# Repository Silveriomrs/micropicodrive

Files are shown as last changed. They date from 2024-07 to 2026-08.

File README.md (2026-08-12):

# MicroPicoDrive
 _An internal replacement for the Sinclair QL Microdrive_

---

UPDATE 12/08/2026

> [!NOTE]
> _New revisions of the driver & cartridges with extra EMI & electrical protection and improving signals. Firmware revision 0.14 improved & stable. Firmware & driver tested, tested last cartridge sub-version 'e' for 4 weeks. Added 3D case (STL) created by Jbizze for short cartridge version to its link_.

> [!TIP]
> All material (Gerbers, BOM, etc) & user guides at the bottom of the page.
---

This branch is for the new 1.4 version of the MicroPicoDrive.
This version was created by Silverio MRS (AKA Popopo) from [Dr. Gusman's original version](https://github.com/gusmanb/micropicodrive).

<p align="center">
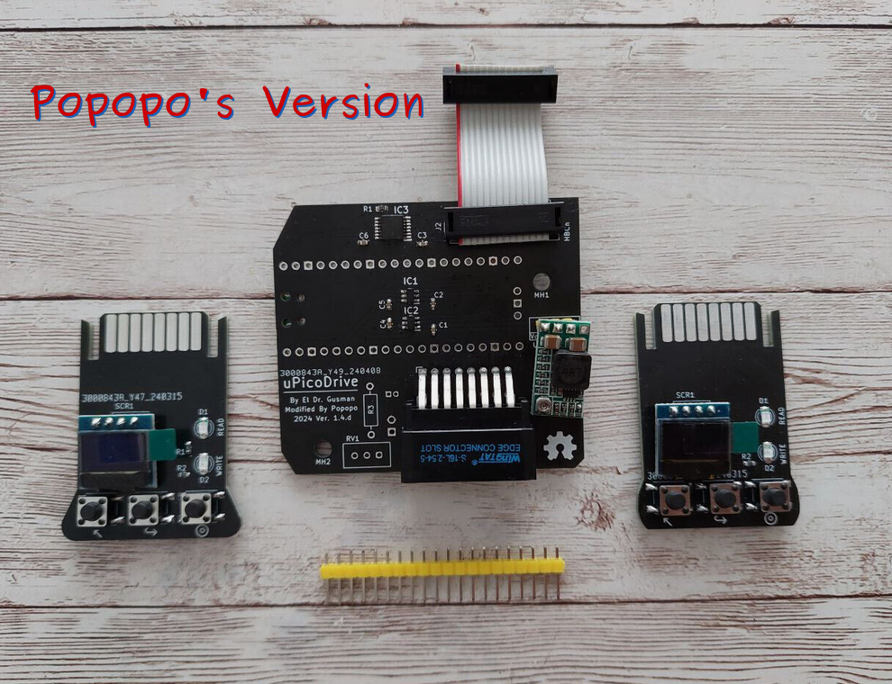
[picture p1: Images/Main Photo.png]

</p>

The image above shows the main driver unit and the 2 cartridges versions with long and short wings (_handles_). Long wings allows to manipulate the cartridge easily reducing mechanical pressure. Shorts instead gives an old fashion shape and allows to be stored into the old (used) black boxes of QL time. Also wearing the 3D case created by Jbizze for the short version cartridge.

<p align="center">
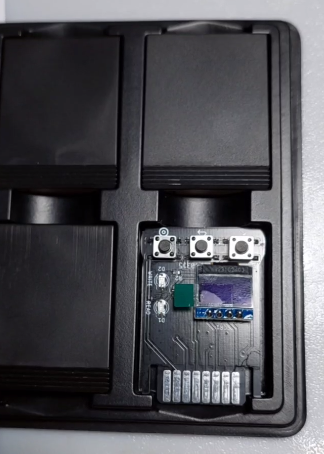
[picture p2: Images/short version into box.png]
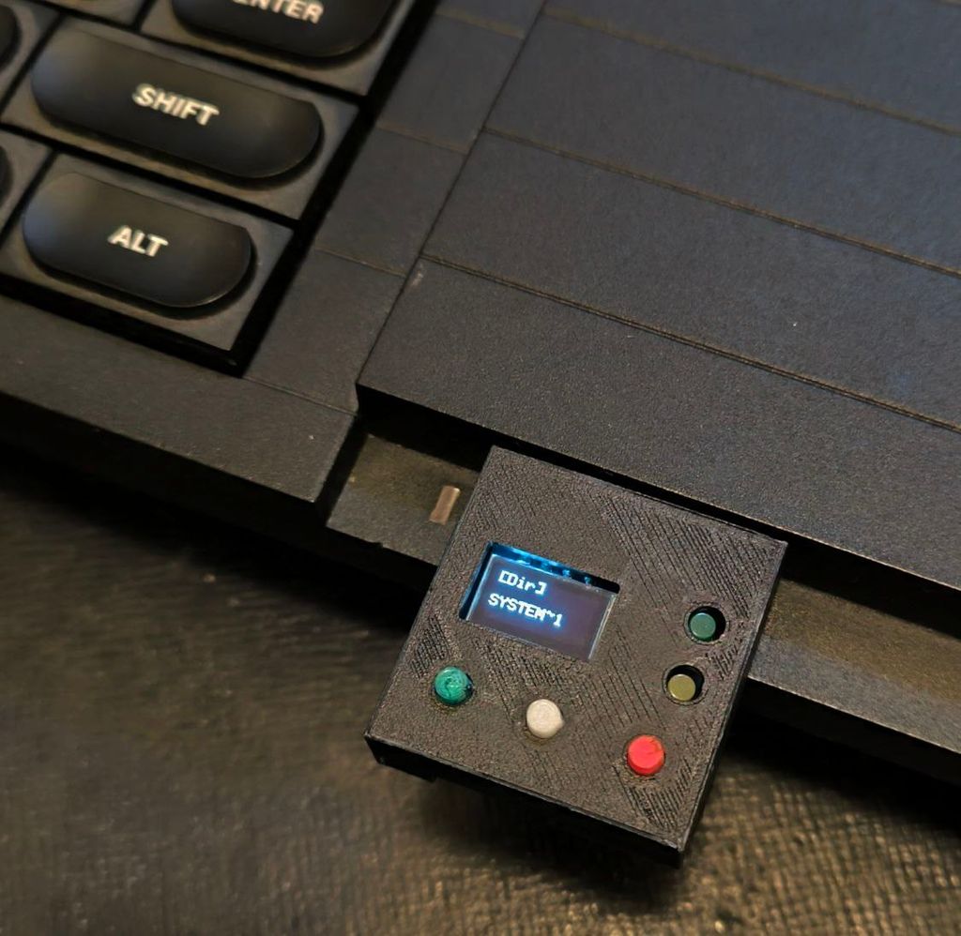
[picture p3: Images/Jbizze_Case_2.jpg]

</p>

---
The next link is a fast view with a demo of the device [Short video demo on Youtube](https://youtu.be/dqscsMP1UB8).

---
_Schema of the driver unit that goes inside the QL._

<p align="center">
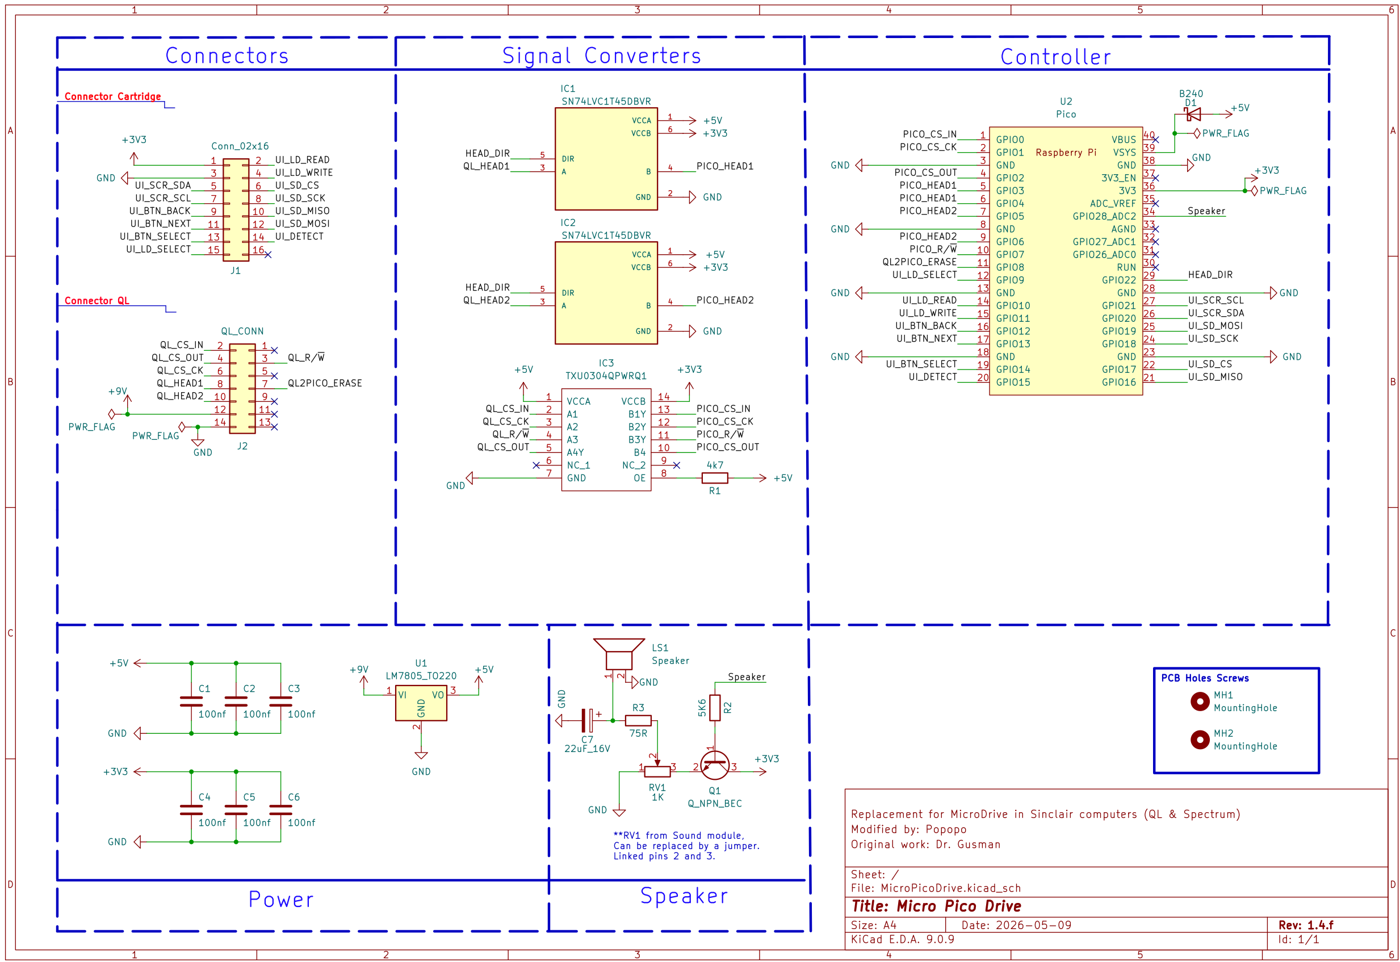
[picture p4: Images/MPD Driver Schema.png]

</p>

---
_Schema of the cartridge that host the microSD and interact with the user._

<p align="center">
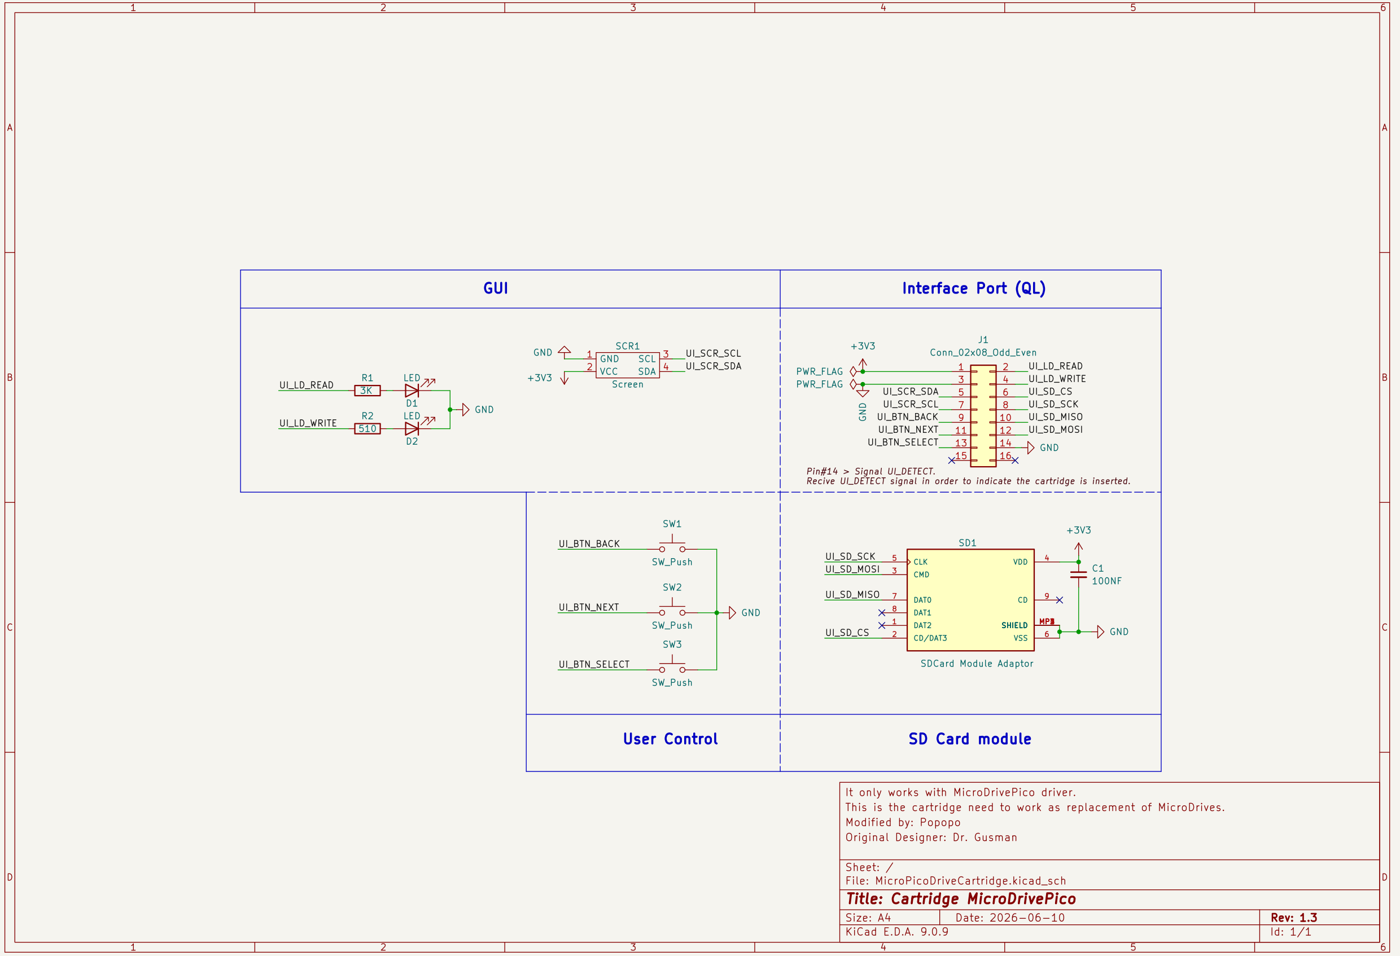
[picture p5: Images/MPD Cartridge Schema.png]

</p>

# Overview
The project was born to give a solution to the old [ZX Microdrive](https://en.wikipedia.org/wiki/ZX_Microdrive) data systems that relies on tape technology. Due to all those system are more than 50 years old and doesn't exist replacements. This system needed a modern replacement stable, very easy to use, flexible and cheap.

The solution presented relay on Hardware and Software combination. With an OpenSource philosophy that could be easily be continued by thirds parties if needed.

The OpenSource & OpenHardware philosophy also responds to the main idea of allowing everyone to built at any time with inexpensive materials, modify or implements different features.

# Objectives of the project
The project was born with the simple goal to be something that anyone could afford and built, what was exceed by far. Yet, there were some details that make the solution not so universal for everyone (_IMO_). Here is where our story begins.

The point is to exploit all the potential of the concept, increasing the number of features of the device, closer to the Gotek concept but powered up with a lot of amazing and desired features.

The first approach was a full success. Whatever in some design points it was limited:
1. It needs some skills and technical hardware acknowledged the system in advance before to build it.
2. Some users with visual difficulties found it unusable due to the small screen. 
3. If you want to distribute it, you can't without knowing previously where the final user want to place it.

Not only **the hardware have been re-shaped**, but **the code/firmware has been refactored, documented (even more) and modularized** in a way that the skills requirements to modify it, become affordable with lower programming skill than before.

It makes sense if the idea is to get chances of scalability and maintenance by the community or recycle the code/hardware in other similar projects.

## Changes over the original project
**New 1.4 design changes:**

+ Place it in any position (MDV_1 or MDV_2) without physical modification.
+ IDC Cable now go straight to the connector on the QL MB.
+ Removed Status LED from Cartridge due to redundancy information with QL Case LED.
+ Add MicroSD footprint to the Cartridge. From now on, it will be cheaper & elegant to build it up.
+ The board is shorter than original one reducing possible case clashes.
+ RaspBerryPi Pico now is soldered on the bottom of the Driver PCB.
+ The Power regulator has changed the place, allowing to the board be placed in any position (MDV_1 or MDV_2).
+ Solved problem with QL Speaker.
+ Solved problem with QL metal chassis under keyboard.
+ Solved problem with right lateral QL case and the regulator.
+ Sound System ready for sound emulation or new features related with it (Working in progress).
+ Added decoupling capacitors to make signals more stable for oLED & mSD.
+ Added schottky diode on the driver that allows program it without disconecting from the main QL PCB. For extra it gives extra protection.
+ Cartridges now has pads retraived for power lines and detection.

## What is coming (TODO functionalities)

Majority of users find the device functional and accomplish their expectations, however still it keeps some nice surprises to powering it up. **All of then can be activated optionally (_opt_)**.

 **Software/firmware**
- [x] Config file to customize preferences (opt).
- [x] New screen modes with bigger fonts (opt).
- [x] Capability of defining a default image to load when turning on the QL or inserting the cartridge (opt).
- [ ] Direct writing (optional).
- [ ] Direct control from the QL OS over the storage system (mSD).

 **Hardware**
- [ ] Sound emulation of the motor (WiP) (opt).
- [ ] MIDI player (WiP) (opt).
- [ ] Bluetooth cartridge and its APP to load images from other devices (PC, Phone, Tablet...) (opt).

### Some extra add-ons that could come
- [ ] External version of the MDP.
- [ ] Interface I MDP version.

---

# Audio visual material
The next videos were made in order to make easier to everyone the understanding about the integration and use on Sinclair QL systems. 
- [Presentation](https://youtu.be/yyiCoWN6E_A) of the project and its initial goals.
- [How to install it](https://youtu.be/CpoAiAcQRLA) points to keep in mind to not damage your Sinclair QL when installing the MDP into it.
- [User's Guide I](https://youtu.be/wyJjXfhqH4E) user's guide to change the firmware, prepare the SD, customize your preferences & browse it.
- [User's Guide II](https://youtu.be/AZIg0KIsFko) shows how to use the basis functions of the MDTools to create a new MDV image, also it shows the most common mistakes.

# Gerbers, Firmware & more 
To download and make the devices on your own using my design you can access to the Gerbers and Firmwares at the release section:
[Releases Gerbers & Firmware](https://github.com/Silveriomrs/micropicodrive/releases/tag/v1.4)

For detailed information about revisions of drivers or cartridges go to see: [Gerbers Descriptions Section](https://github.com/Silveriomrs/micropicodrive/tree/1.4/Hardware%201.4%20(By%20Popopo)/Gerbers)

For i/BOM check directory: [Schmems & i/BOMs](https://github.com/Silveriomrs/micropicodrive/tree/1.4/Hardware%201.4%20(By%20Popopo)/Schems%20&%20BOMs)

For 3D case created by Jbizze for short cartridge version: [STL from Thingverse](https://www.thingiverse.com/thing:6886864) or to Download directly: [Releases Gerbers & Firmware](https://github.com/Silveriomrs/micropicodrive/releases/tag/v1.4)

<p align="center">
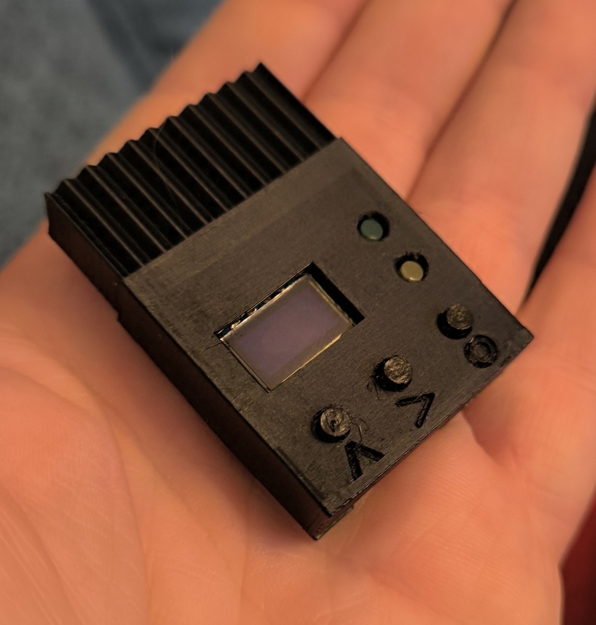
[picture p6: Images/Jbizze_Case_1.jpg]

</p>

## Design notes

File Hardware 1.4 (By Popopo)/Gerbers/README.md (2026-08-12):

# Gerbers Description
 _Secction to describe each Gerber option_

---

UPDATE 12/08/2026

> [!NOTE]
> _New revisions of the driver (h) & cartridges (e) with extra EMI & electrical protection and improving signals._.

There system is compound by a driver and its cartridge. It is always possible to improve somehow some elements or factors, so a alive project requires time to time some new releases (when they are justified). 

Sometimes changes are to improve signals, ESD/EMI factors, or power. In other cases it is to bring to the users more options and better implementation/building.

## Driver
Always the last version will result in the best option, but sometimes those changes are not necesesary. If you don't know what to use, choose the newest version. If you are happy with lower protection level or not using some hardware elements you know won't be useful for you (that means you have a good control of what you are doing), choose the alternative from available Gerbers.

<p align="center">
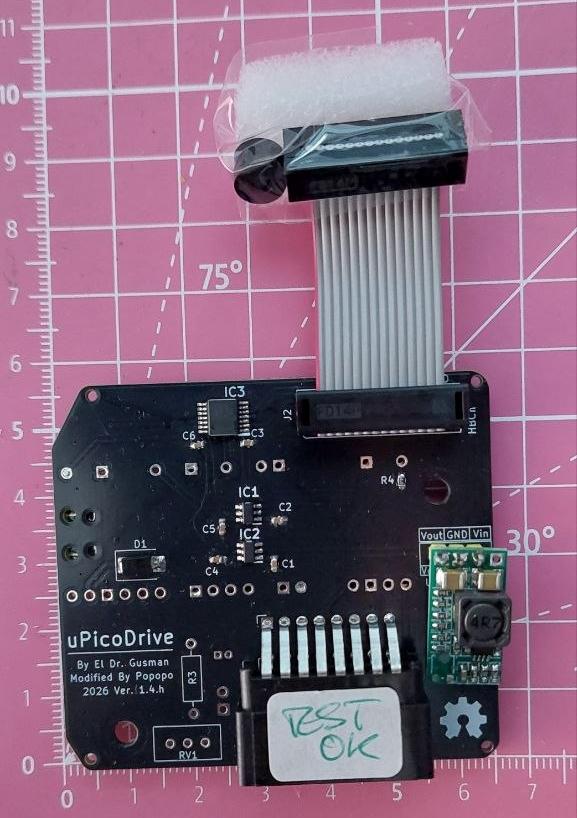
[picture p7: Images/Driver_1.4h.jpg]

</p>

## Cartridge
Here is where a final user could feel confuse due to variety of options :) , let's see it in an direct & easy way.

**There are 2 main different shapes** for cartridge which main difference is the size of the handles: **Short** and **Large** one. 

<p align="center">
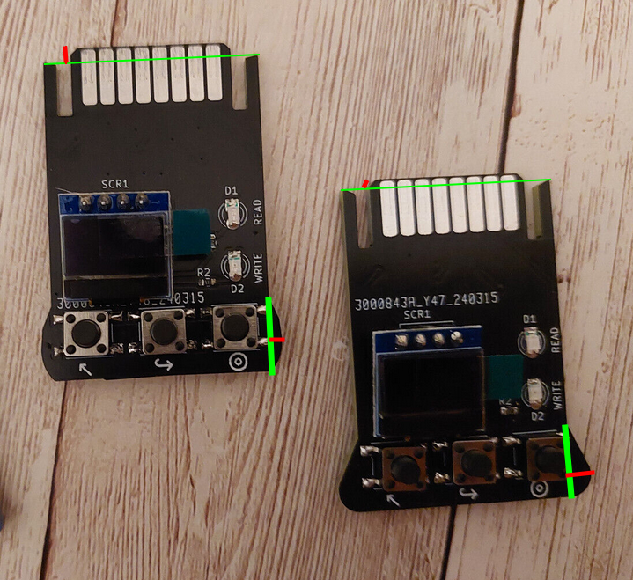
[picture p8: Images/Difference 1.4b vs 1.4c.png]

</p>

The short is more than enough to handle it easily and fits into the old black plastic box where Sinclair used to give PSION software.

The large is easier to extract/insert than the short one, for hands like mine it is nicer. 

How it is designed allows you to use SMD Leds or TH Leds (giving more retro feeling). So when mounting the LEDs you can choose what suits more more to your personality. Keep in mind that schemas reflects resistos values for the LEDs acording to the specs of the used LEDs by myself. TH versions may be happy with 1K resistors but always check it out by yourself according to luminance, max current and max current that RP2040 may source.

<p align="center">
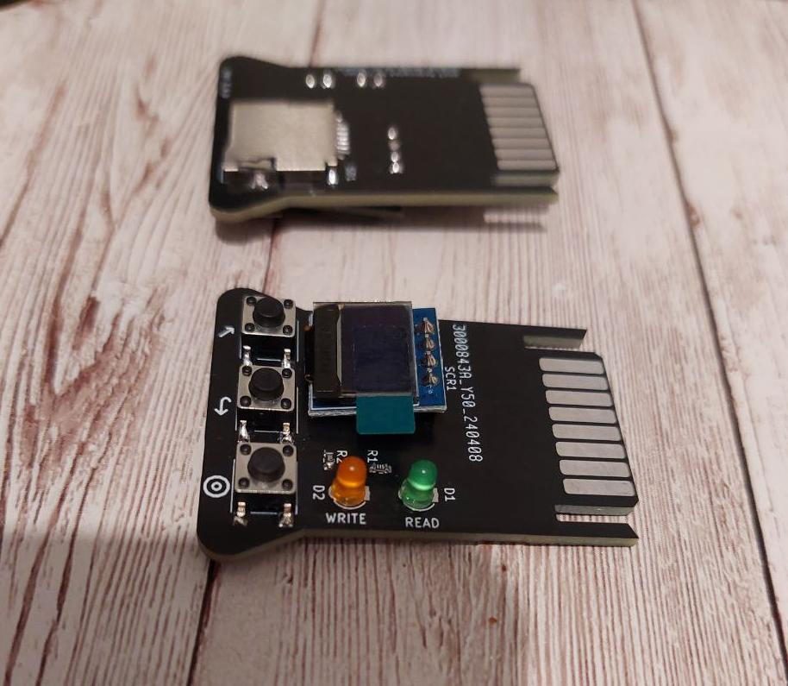
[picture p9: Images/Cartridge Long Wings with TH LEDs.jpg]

</p>

Finally, recently I have made some changes for cartridges in order to improve electrical manipulation, so a good part of the pads that were connection to the EDGE socket now are retreived in order to ensure Power Lines are connected before the signals. It is by now working great, but old version has been working for 3 years with non stop (and with HASL finishing).

<p align="center">
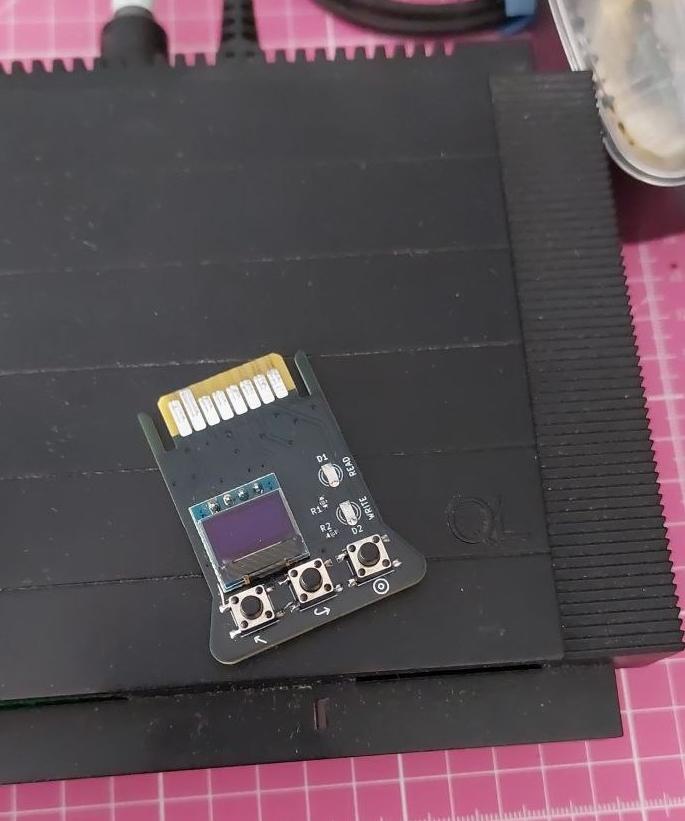
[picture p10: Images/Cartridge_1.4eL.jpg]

</p>

**Pros**: Safer electrically case now power pads connect firstly (specially GDN), the EDGE contacts now scratch less copper/HASL surface when inserting/removing operation and now it goes on a FR4 fiber that is harder to scratch than regular pads.

**Cons**: Has not been tested for years like previous one.

If you are going to produce your own PCBs or use any maker like PCBWay or JLCPCB, you can choose a better finish for EDGE connector and PADs, like ENIG or HARD Gold. But be aware, IMHO that is not justified at all, is too expensive for the service of this system that have been working for years without any problem at innexpensive price. HASL is more than enough like all our machines have been produced (back ports on ZX, QL, MSX, CPC... long list). I recommend HASL: cheap & more than good for the service.

Trust me, you will more than happy with any option you choose. :)

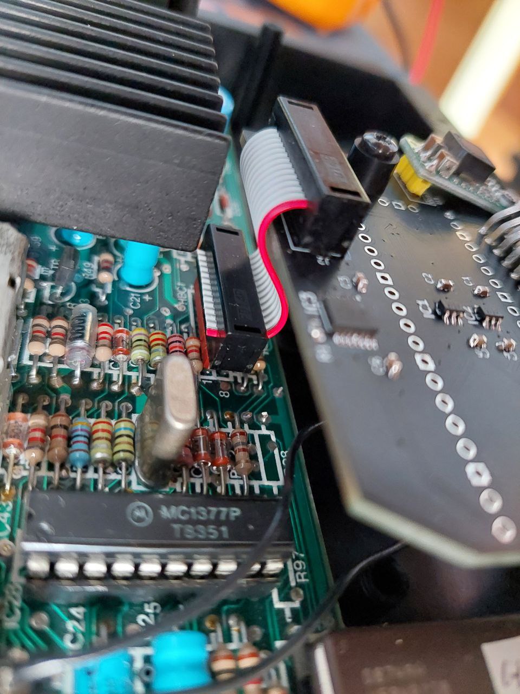
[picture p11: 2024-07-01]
Images/Insalled MDP Lateral.jpg

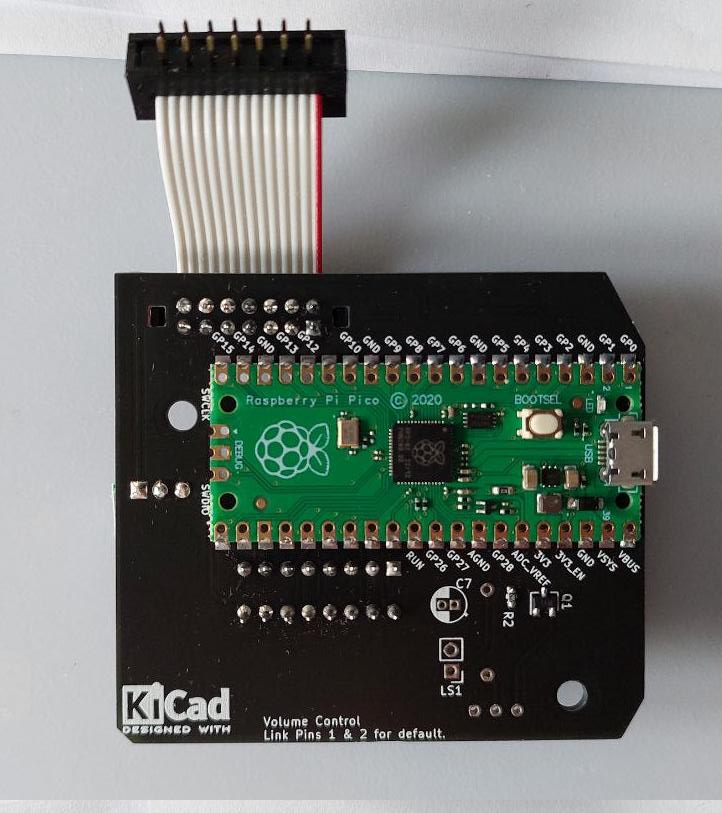
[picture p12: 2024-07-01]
Images/Drive bottom.jpg

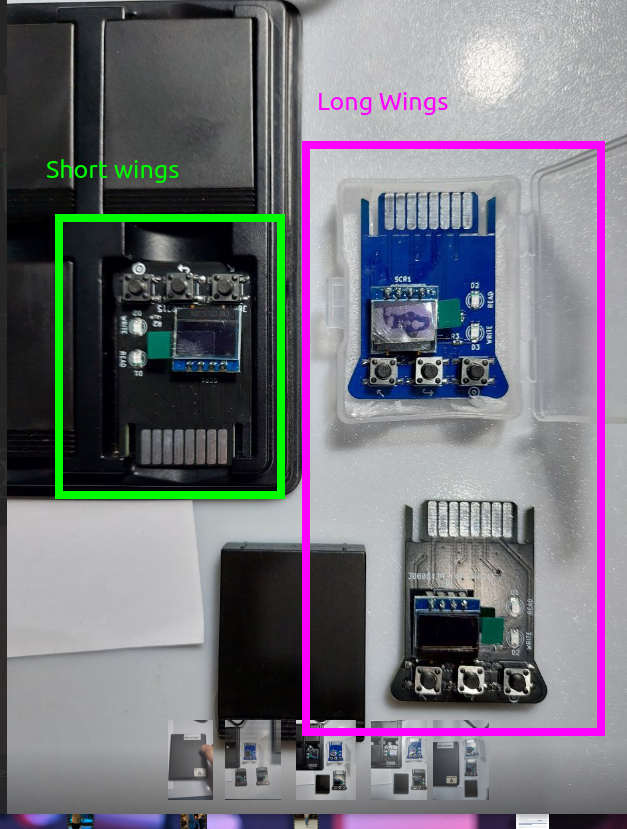
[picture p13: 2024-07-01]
Images/Long vs short wings.png

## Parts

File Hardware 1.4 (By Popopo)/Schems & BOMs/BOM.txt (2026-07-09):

--Main unit--

C1 to C6: 100nf, 0603
R1: 4k7, 0603
R4: 1K, 0603
IC1, IC2: SN74LVC1T45DBVR
IC3: TXU0304PWR
U1: 7805 TO220 or DC/DC buck module
D1:	B240 D_SMB (higly recommended but may be 1A diode instead 2A. It is optional and may be skiped: linking both sides with a jumper)
U2: Raspberry pico
J1: Card edge connector, 2x8p, 2.54mm, curved pin.
J2: Male IDC, 2x7p, 2.54mm (check assembly instructions for more details)

(Optional sound pre.module)
R2: 5K6, 0603
Q1: NPN MMBT3904 / 2N3904 1AM SOT23  40V 200mA

--Cartridge--

R1 to R2: 1k, 0603  (It depends on the specs of each led)
C1: 100nf, 0603
SW1 to SW3: SMD microswitch push button
SCR1: 0'49" SD1306 module
D1 to D2: 3mm LED (green and yellow/red)
SD1: SD card socket module

--Buy links--

SN74LVC1T45:		https://es.aliexpress.com/item/1005004345377244.html
TXU0304PWR:  		https://es.aliexpress.com/item/1005004929752779.html
DC/DC buck converter: 	https://es.aliexpress.com/item/1005005343434991.html
Card edge connector:	https://es.aliexpress.com/item/1005001884522039.html
IDC connector:		https://es.aliexpress.com/item/1005001835803614.html
Screen module:		https://es.aliexpress.com/item/1005003874700775.html
SD card module:		https://es.aliexpress.com/item/32791255542.html

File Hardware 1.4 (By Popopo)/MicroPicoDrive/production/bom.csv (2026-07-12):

Designator | Footprint | Quantity | Value | LCSC Part #
C1, C2, C3, C4, C5, C6 | 0603 | 6 | 100nf
C7 | CP_Radial_D4.0mm_P1.50mm | 1 | 22uF_16V
D1 | D_SMB | 1 | B240
IC1, IC2 | SOT95P280X145-6N | 2 | SN74LVC1T45DBVR
IC3 | TXU0304QPWRQ1 | 1 | TXU0304QPWRQ1
J1 | Edge_connector_02x08 | 1 | Conn_02x16
J2 | CONN_IDC_2x7 | 1 | QL_CONN
LS1 | PinHeader_1x02_P2.54mm_Vertical | 1 | Speaker
MH1, MH2 | MountingHole_3.5mm_safe_screw_area | 2 | MountingHole
MH_S1, MH_S2, MH_S3, MH_S4 |  | 4 | MountingHole
Q1 | SOT-23W | 1 | Q_NPN_BEC
R1 | 0603 | 1 | 4k7
R2 | 0603 | 1 | 5K6
R3 | R_Axial_DIN0207_L6.3mm_D2.5mm_P10.16mm_Horizontal | 1 | 75R
R4 | 0603 | 1 | 1K
RV1 | Potentiometer_Bourns_3296W_Vertical | 1 | 1K
U1 | TO-220-3_Vertical | 1 | LM7805_TO220
U2 | RPi_Pico_SMD_TH | 1 | Pico

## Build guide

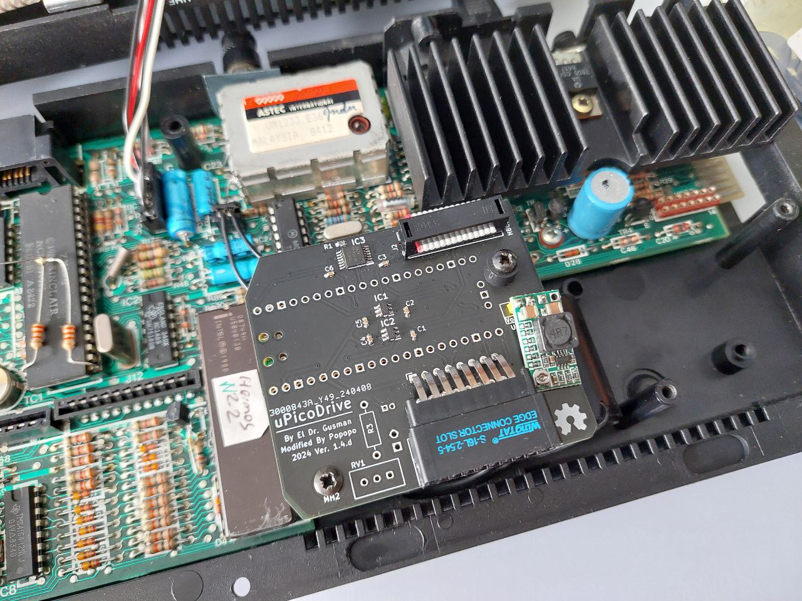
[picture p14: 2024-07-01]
Images/Installed MDP Top.jpg

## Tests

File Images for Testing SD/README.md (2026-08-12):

# Description of Images (MDV & MDP)
## _Overview_

> [!NOTE]
> _Images served only for testing purpose_

The microdrives images presented here are only for testing purpose. Thus you can find software ready to load into your QL system and others that need some works with [MDTools (From Dr. Gusman)](https://github.com/gusmanb/micropicodrive/releases/tag/V1.0.0.0) or another similar tool.

In particular part of the PSION software is not prepared yet to be loaded successfully in a real QL with Minerva ROM (but Abacus). It allows you to understand the complexity and how MDV images are required to be adapted for emulators or some devices. What means it is not related with an specific hardware solution but how datas are modified by some OSes (_ie. MS Windows_) when they are stored in its file system or even the QL ROM you are using.

The idea is to give few images to play around directly with QL and enjoy the MicroDrivePico solution (also name here as MPD). Others to learn to control the MDTools and how the QL ecosystem fight between different formats and issues from a highly complex legacy reasons.

If you are new in QL ecosystem, be aware that due to some OS treatment with storage systems (MS Windows mainly) it requires some "headers" or extra info related with data space and "Magic Fields" that exceed the purpose of this info. All that can be solved with the mentioned tools above.

Also, for newbies there is a empty and formatted image that you can use (copy and paste) to use like real Microdrives to save your data or use like you were using real one.

I hope you're enjoying this beautiful solution. :)

## Directory: Main
No particular hardware needs for those images.

| Image | Ready? | Type | Overview |
| --- | :--: | :--: | ---- |
| ABACUS.MDV | Yes | Office | Developed by PSION software |
| Chess.mdv | Yes | Game |  |
| pacman_patched | No | Game | The image has not right checksum |
| Pitman.MDV | Yes | Game | Developed by Andrei |
| Space Invaders(PD).mdv | Yes | Game |  |
| MyBasic.mdv | Yes | Util | Basic cartridge with a Basic sample |
| newcart.mdv | Yes | Util | Formatted MDV image for your use |
| **CONFIG.CFG** | Yes | Util | _Optional file_ **required to customize the device** |

## Directory: PSION_4
All those belongs to PSION suit. All of them work properly in a stock QL with MDPs. They have the headers 'fixed' with the data attribute saved. They could serve like comparation with the structure image with their twins into the Fail folder.

| Image | Ready? | Type | Overview |
| --- | :--: | :--: | ---- |
| ABACUS.MDV | Yes | Office | Developed by PSION software |
| ARCHIVE.MDV | Yes | Office | Developed by PSION software |
| EASEL.MDV | Yes | Office | Developed by PSION software |
| QUILL.MDV | Yes | Office | Developed by PSION software |

## Directory: FAIL
All those belongs to PSION suit. Those images are to test and play around with convertir MDVs subformats and doesn't work without 'fix' them. Specially to use Dr. Gusman tools or Johan Engdhal's tool. 

| Image | Ready? | Type | Overview |
| --- | :--: | :--: | ---- |
| ARCHIVE.MDV | No | Office | Developed by PSION software |
| EASEL.MDV | No | Office | Developed by PSION software |
| QUILL.MDV | No | Office | Developed by PSION software |

## Directory: Demos
**Some hardware requirements could be need**. For example: Sound cards, expansion cards, memory expansion, new versions of the demos (due to it presented bugs in the time where they were published), etc. You should be aware of those matters and find the requirements/updates to play around with them.

This directory contains some others with files of many kinds to play around about converting them into MDV images, changing headers and so on.

| Image | Ready? | Type | Overview |
| --- | :--: | :--: | ---- |
| m86K24 | ? | Demo | Sound card/Specific ROM? |
| smfxteam.mdv | ? | Demo | Sound card/Specific ROM? |
| qldrive11 | X | Dir | Multiple files for testing |
| war | X | Dir | Multiple files for testing |
| WB21_tk2.MDV | yes | Demo | Amiga Workbench demo. Requires memory expansion and TK2 |

**Directories qldrive11 & war**

Those directories contains files of a vary of types in order to play around, and may or may not be packed into MDV images, changing headers and so on.

> [!NOTE]
> Those dirs are placed here to check out how the browsing system of the MDPs is right, ignores not compatible files or contains bugs. So its purpose is not to be loaded into a real QL.

## Directory: more
This folder contain some legacy images from original project (Dr. Gusman's github). Not a specific role yet.

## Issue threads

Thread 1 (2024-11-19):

bad or changed medium

Silveriomrs, 2024-11-19:
With RC11 (probably some previous versions) some cases provoke the message "bad or changed medium".

It may happen when the option Autoload is used and trying to save changes on the MDV image.
It is localized and working in process to release RC12 with the bugfix and other programmed features.

The Script to provoke the issue is as follow:

- power on
- select chess cartridge [M button] to select, [R button] to load
- [F2]
- load chess => OK
- play chess => OK
- RESET
- deselect chess cartridge [L button]
- [F2]
- select chess cartridge [M button] to select, [R button] to load
```basic
dir mdv1_
copy mdv1_BOOT to mdv1_BOOT_SAV
delete mdv1_BOOT
dir mdv1_
ed
```
- type a little basic program and press [Esc]
```basic
cls
run
save mdv1_demo_bas
dir
new
list
load mdv1_demo_bas
run
```
- save chess cartridge [R button]
- power off
- wait 6s
- power on
- select chess cartridge [M button] to select, [R button] to load

- [F2]
```basic
dir mdv1_
load mdv1_demo_bas
run
dir mdv1_
lrun mdv1_BOOT_SAV => bad or changed medium
```
- reset
```basic
dir mdv1_
load mdv1_demo_bas
run
load mdv1_BOOT_SAV
list
dir mdv1_
EW mdv1_chess => bad or changed medium
```

Silveriomrs, 2024-12-15:
**Solved in RC12**

In previous version RC11 **it doesn't present a problem when not using Autoload option.**

Closed 2024-12-15.

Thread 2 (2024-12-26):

Corruption on images

Silveriomrs, 2024-12-26:
### Undesired modification of the sectors on MDVs images.

**Resume**
After solving another that produced bad media error,
appeared another one that seems to be the root of many problems related. Also may be related with the other issued already solver partially.

It produce errors in MDVs images modifying in a weird way the size and used sectors in every iteration, what should not happen. Should be?
Those errors could appear in failing operation or bad media. But the clue is how sectors are modified. All of it, without persistence of the image. I mean, with the image loaded on the Pico but not saving changes on the microSD.

This last point should discard a failing operation in writing functions on the microSD (not the functions for writing the image in the rpi2040 memory).

**Keys**
My suspect is it is related with some original functions that fill the length of the MDV on saving/modifying operations.

**Images of the issue**

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

Silveriomrs, 2025-05-10:
After observing some original Microdrives working,
**I understood that it is a legacy issue from the QL and not related with the device**.

So the issue is not a problem of changing the size (sectors) in each format badly managed by MDPs.
I keep this issue open only to dig deeper about the **Bad or changed medium error**.

Silveriomrs, 2025-05-25:
Updating the issue,
It happens when a MDV image is taken and formated again. From this point on the number of sectors and (probably another king of inner data of the format) doesn't match what metadatas has for this MDV image any more. And starts to shows this bad medium error.

So in order to solve or use new cartridge you can:

1. To use the empty image on the shared for testing MDVs images
2. Use any MDV image that works for you, and delete all files inside, make changes permanent and this image duplicate it as many time as new cartridges you want.
3. To create a new MDV image with QEmulator or another one that create compatible QLAY MDV image.
4. To use MDTools (available in this repository too) to create a new MDV image with no files.

In any of those cases, DO NOT FORMAT the MDV image.

I'll work on it to solve this problem anyway allowing direct format from QL.

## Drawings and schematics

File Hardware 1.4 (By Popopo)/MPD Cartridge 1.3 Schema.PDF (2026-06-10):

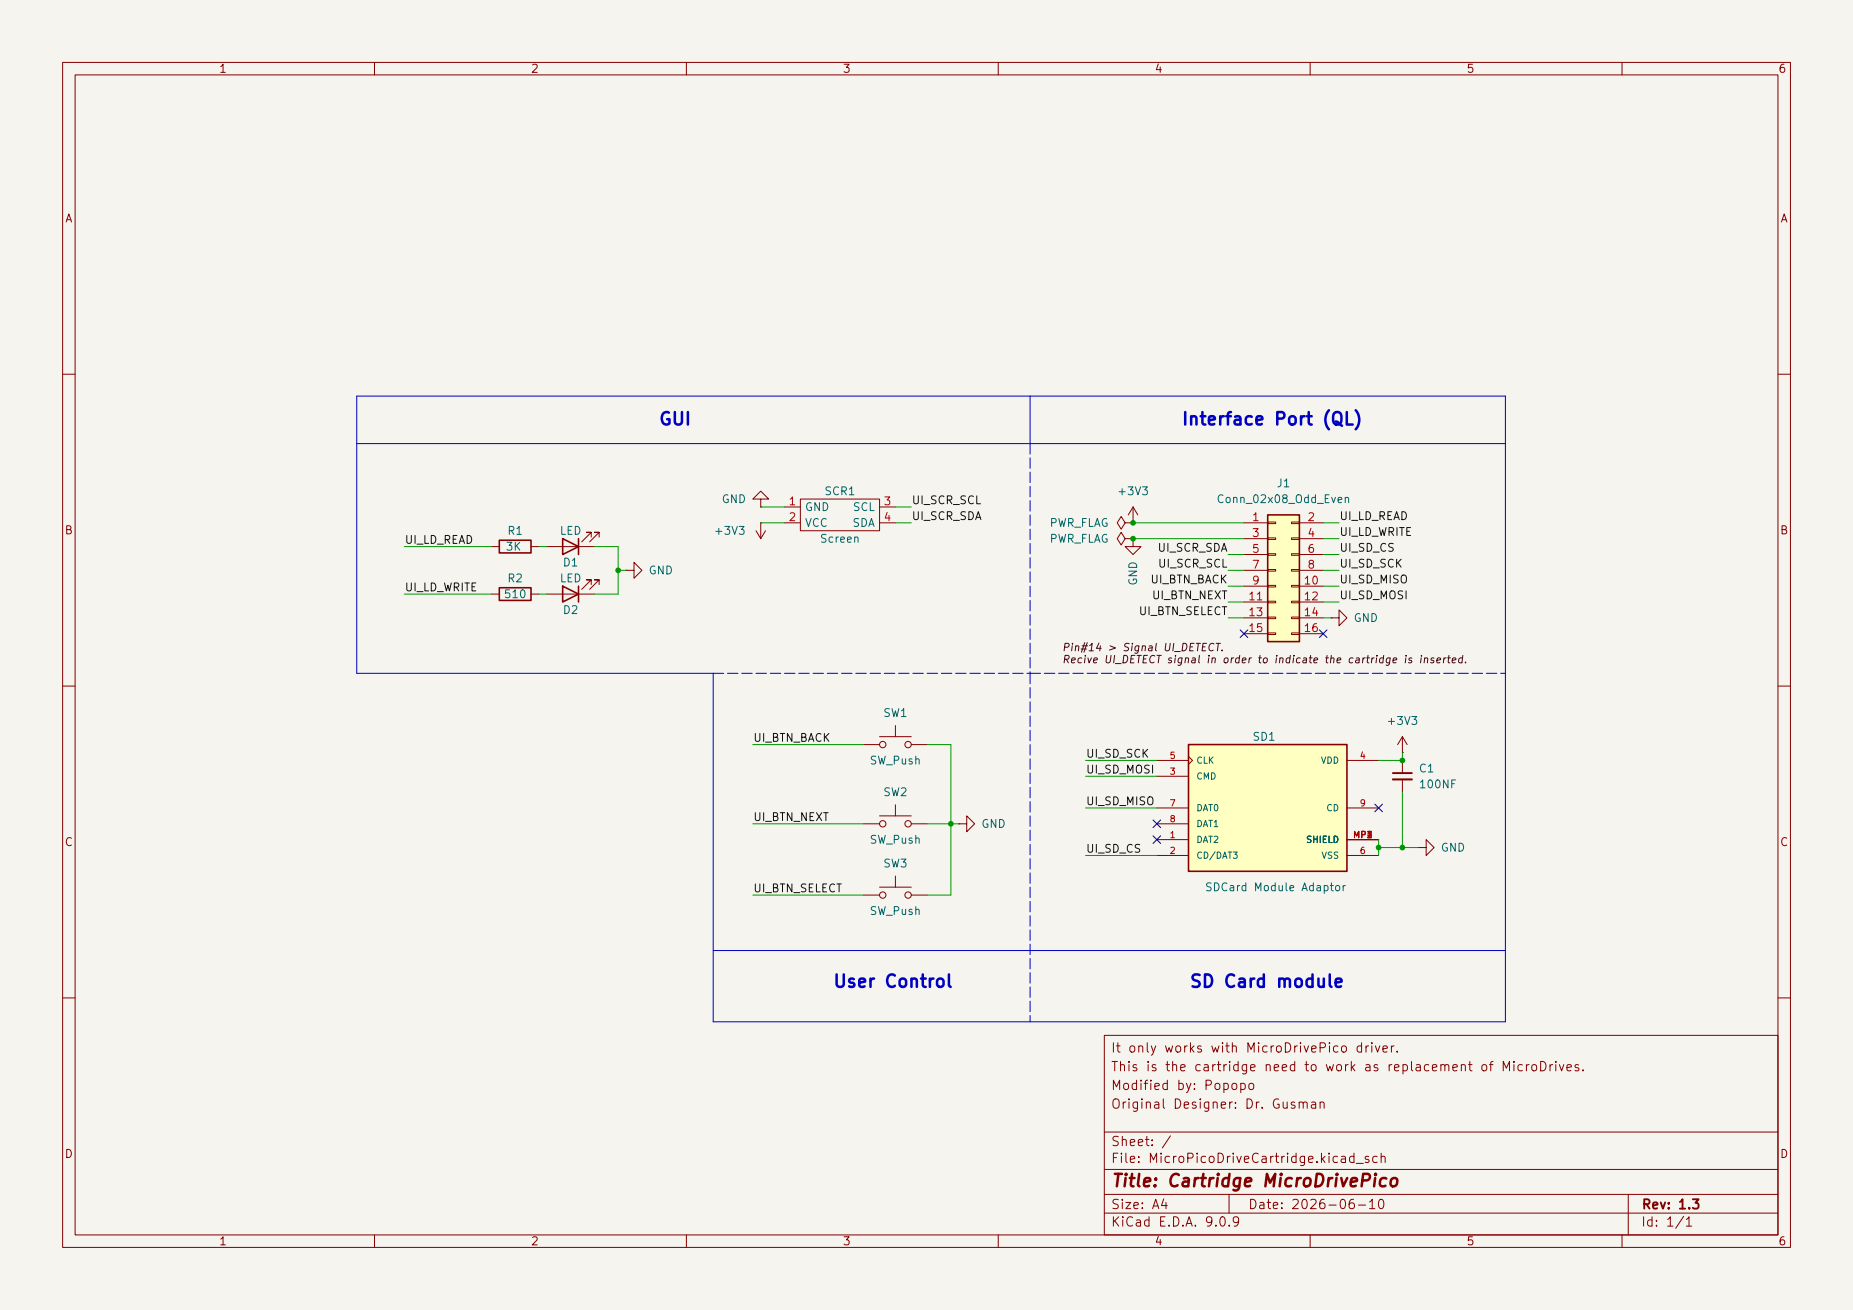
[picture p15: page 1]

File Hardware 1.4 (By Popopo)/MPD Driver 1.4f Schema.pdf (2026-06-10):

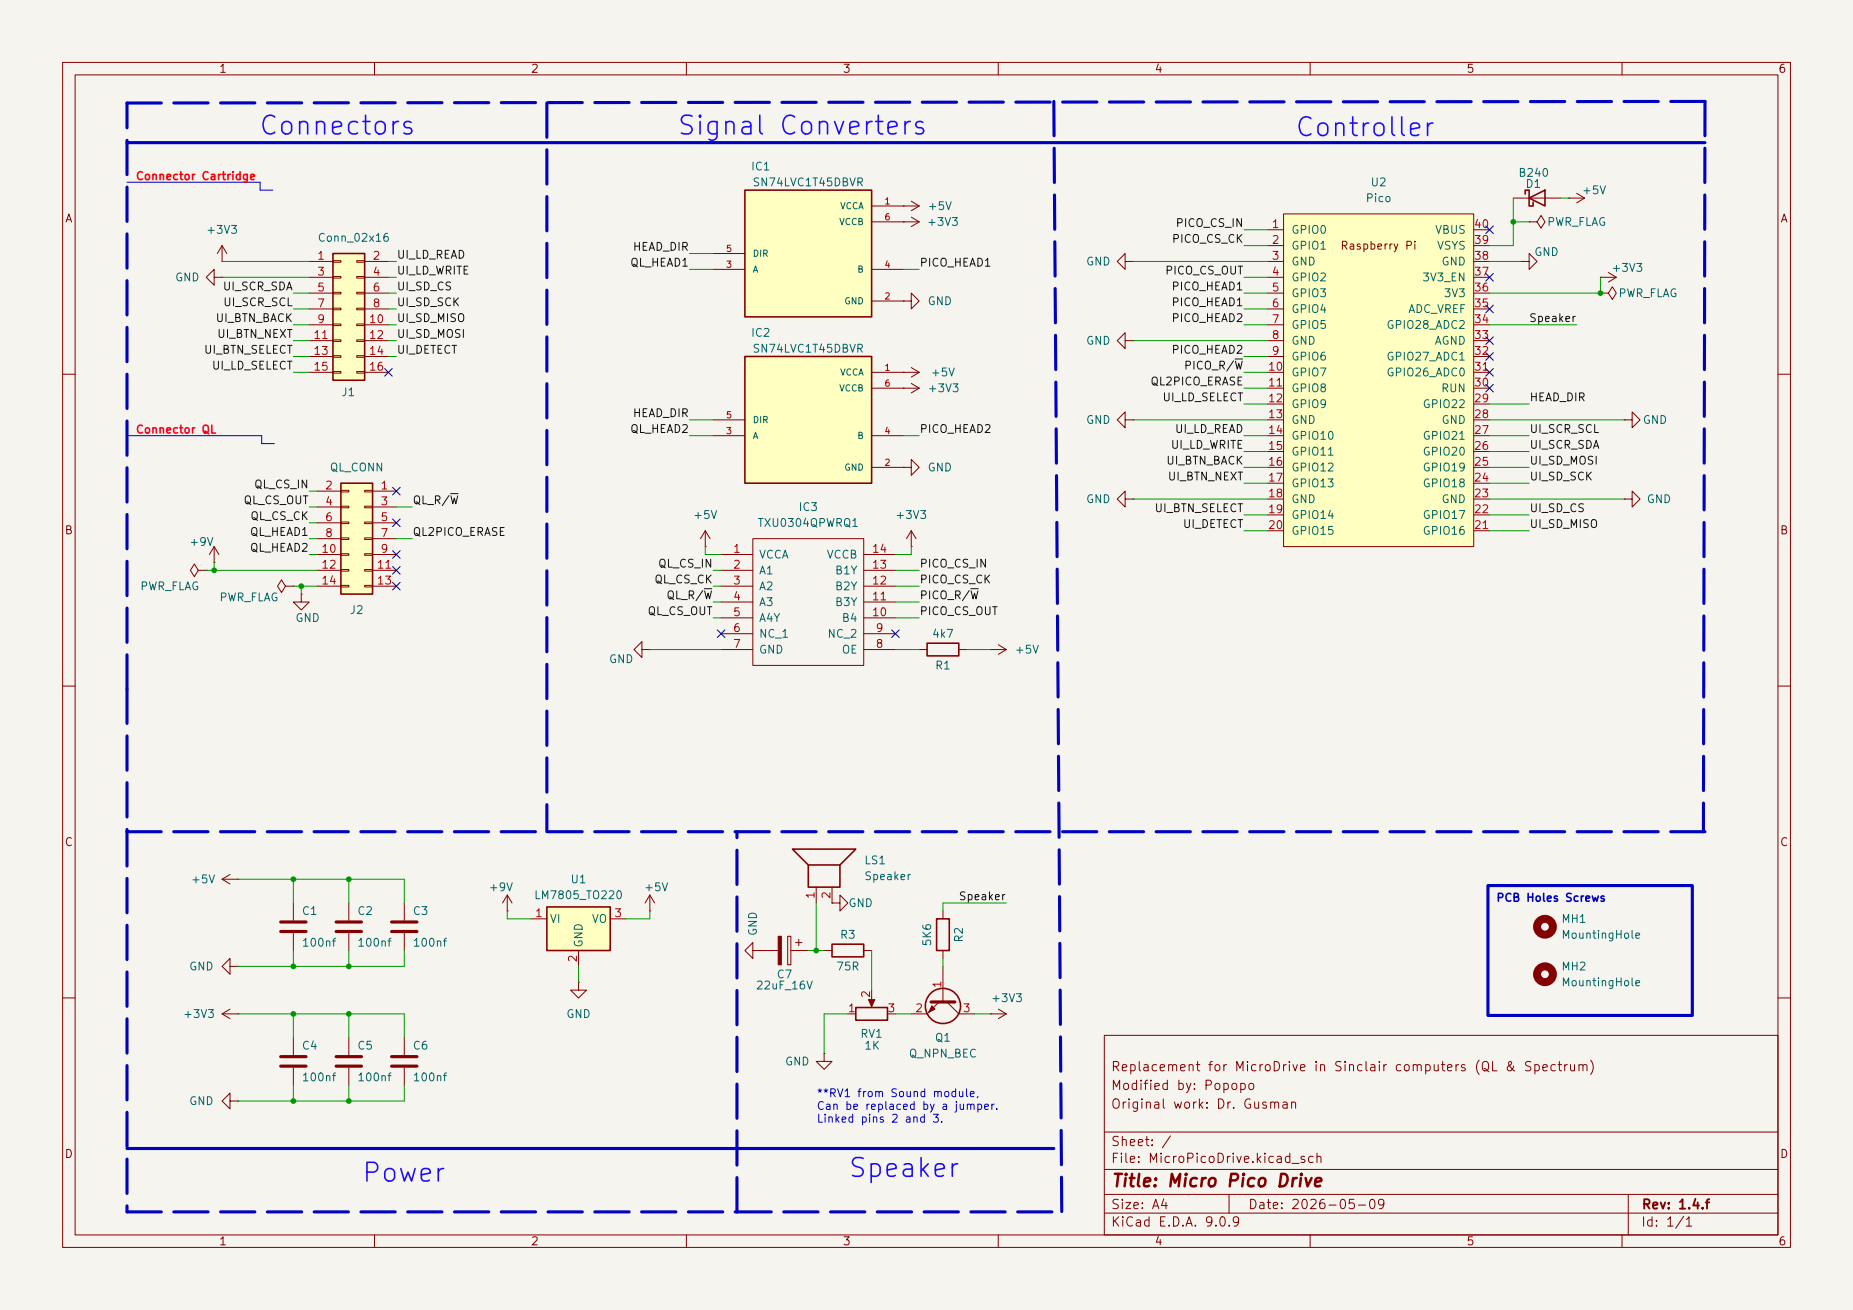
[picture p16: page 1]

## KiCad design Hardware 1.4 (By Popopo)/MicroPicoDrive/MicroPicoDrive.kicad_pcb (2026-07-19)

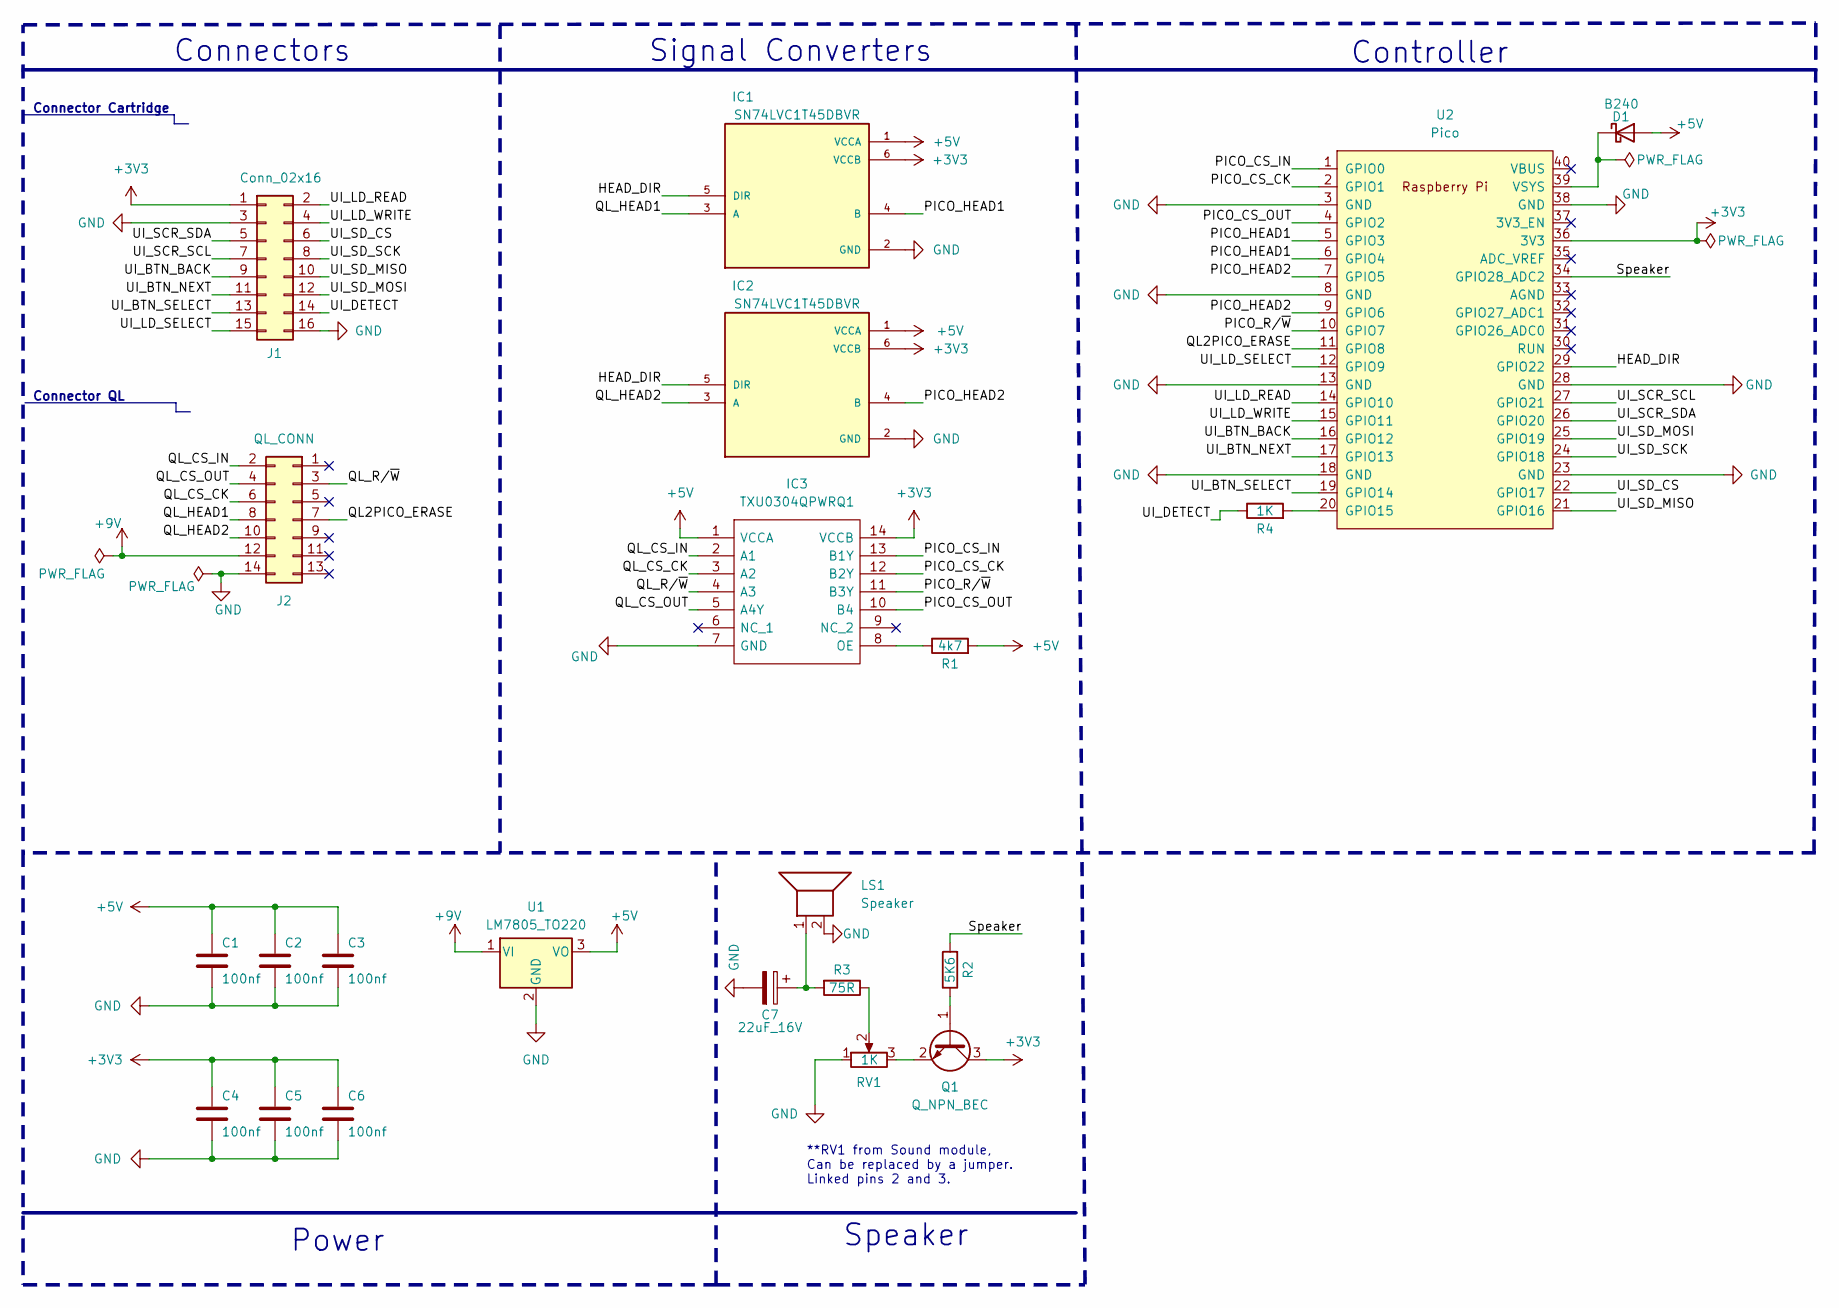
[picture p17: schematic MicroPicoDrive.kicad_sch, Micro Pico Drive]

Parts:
C1, C2, C3, C4, C5, C6: 100nf; C_0603_1608Metric
C7: 22uF_16V; CP_Radial_D4.0mm_P1.50mm
D1: B240; D_SMB
IC1, IC2: SN74LVC1T45DBVR; SOT95P280X145-6N; Mouser Part Number 595-SN74LVC1T45DBVR
IC3: TXU0304QPWRQ1; Mouser Part Number 595-TXU0304QPWRQ1
J1: Conn_02x16; Edge_connector_02x08
J2: QL_CONN; CONN_IDC_2x7
LS1: Speaker; PinHeader_1x02_P2.54mm_Vertical
Q1: Q_NPN_BEC; SOT-23W
R1: 4k7; R_0603_1608Metric
R2: 5K6; R_0603_1608Metric
R3: 75R; R_Axial_DIN0207_L6.3mm_D2.5mm_P10.16mm_Horizontal
R4: 1K; R_0603_1608Metric
RV1: 1K; Potentiometer_Bourns_3296W_Vertical
U1: LM7805_TO220; TO-220-3_Vertical
U2: Pico; RPi_Pico_SMD_TH

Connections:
+3V3: C4.1, C5.1, C6.1, IC1.6 (VCCB), IC2.6 (VCCB), IC3.14 (VCCB), J1.1, Q1.3 (C), U2.36 (3V3)
+5V: C1.1, C2.1, C3.1, D1.2 (A), IC1.1 (VCCA), IC2.1 (VCCA), IC3.1 (VCCA), R1.2, U1.3 (VO)
+9V: J2.12, U1.1 (VI)
/HEAD_DIR: IC1.5 (DIR), IC2.5 (DIR), U2.29 (GPIO22)
/PICO_CS_CK: IC3.12 (B2Y), U2.2 (GPIO1)
/PICO_CS_IN: IC3.13 (B1Y), U2.1 (GPIO0)
/PICO_CS_OUT: IC3.10 (B4), U2.4 (GPIO2)
/PICO_HEAD1: IC1.4 (B), U2.5 (GPIO3), U2.6 (GPIO4)
/PICO_HEAD2: IC2.4 (B), U2.7 (GPIO5), U2.9 (GPIO6)
/PICO_R/~W: IC3.11 (B3Y), U2.10 (GPIO7)
/QL2PICO_ERASE: J2.7, U2.11 (GPIO8)
/QL_CS_CK: IC3.3 (A2), J2.6
/QL_CS_IN: IC3.2 (A1), J2.2
/QL_CS_OUT: IC3.5 (A4Y), J2.4
/QL_HEAD1: IC1.3 (A), J2.8
/QL_HEAD2: IC2.3 (A), J2.10
/QL_R/~W: IC3.4 (A3), J2.3
/Speaker: R2.2, U2.34 (GPIO28_ADC2)
/UI_BTN_BACK: J1.9, U2.16 (GPIO12)
/UI_BTN_NEXT: J1.11, U2.17 (GPIO13)
/UI_BTN_SELECT: J1.13, U2.19 (GPIO14)
/UI_DETECT: J1.14, R4.1
/UI_LD_READ: J1.2, U2.14 (GPIO10)
/UI_LD_SELECT: J1.15, U2.12 (GPIO9)
/UI_LD_WRITE: J1.4, U2.15 (GPIO11)
/UI_SCR_SCL: J1.7, U2.27 (GPIO21)
/UI_SCR_SDA: J1.5, U2.26 (GPIO20)
/UI_SD_CS: J1.6, U2.22 (GPIO17)
/UI_SD_MISO: J1.10, U2.21 (GPIO16)
/UI_SD_MOSI: J1.12, U2.25 (GPIO19)
/UI_SD_SCK: J1.8, U2.24 (GPIO18)
GND: C1.2, C2.2, C3.2, C4.2, C5.2, C6.2, C7.2, IC1.2 (GND), IC2.2 (GND), IC3.7 (GND), J1.3, J1.16, J2.14, LS1.2, RV1.1, U1.2 (GND), U2.3 (GND), U2.8 (GND), U2.13 (GND), U2.18 (GND), U2.23 (GND), U2.28 (GND), U2.38 (GND)
unnamed: C7.1, LS1.1, R3.2
unnamed: D1.1 (K), U2.39 (VSYS)
unnamed: IC3.8 (OE), R1.1
unnamed: Q1.1 (B), R2.1
unnamed: Q1.2 (E), RV1.3
unnamed: R3.1, RV1.2
unnamed: R4.2, U2.20 (GPIO15)

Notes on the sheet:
Connector QL
Controller
Power
Connector Cartridge
Speaker
Connectors
Signal Converters
**RV1 from Sound module, Can be replaced by a jumper. Linked pins 2 and 3.

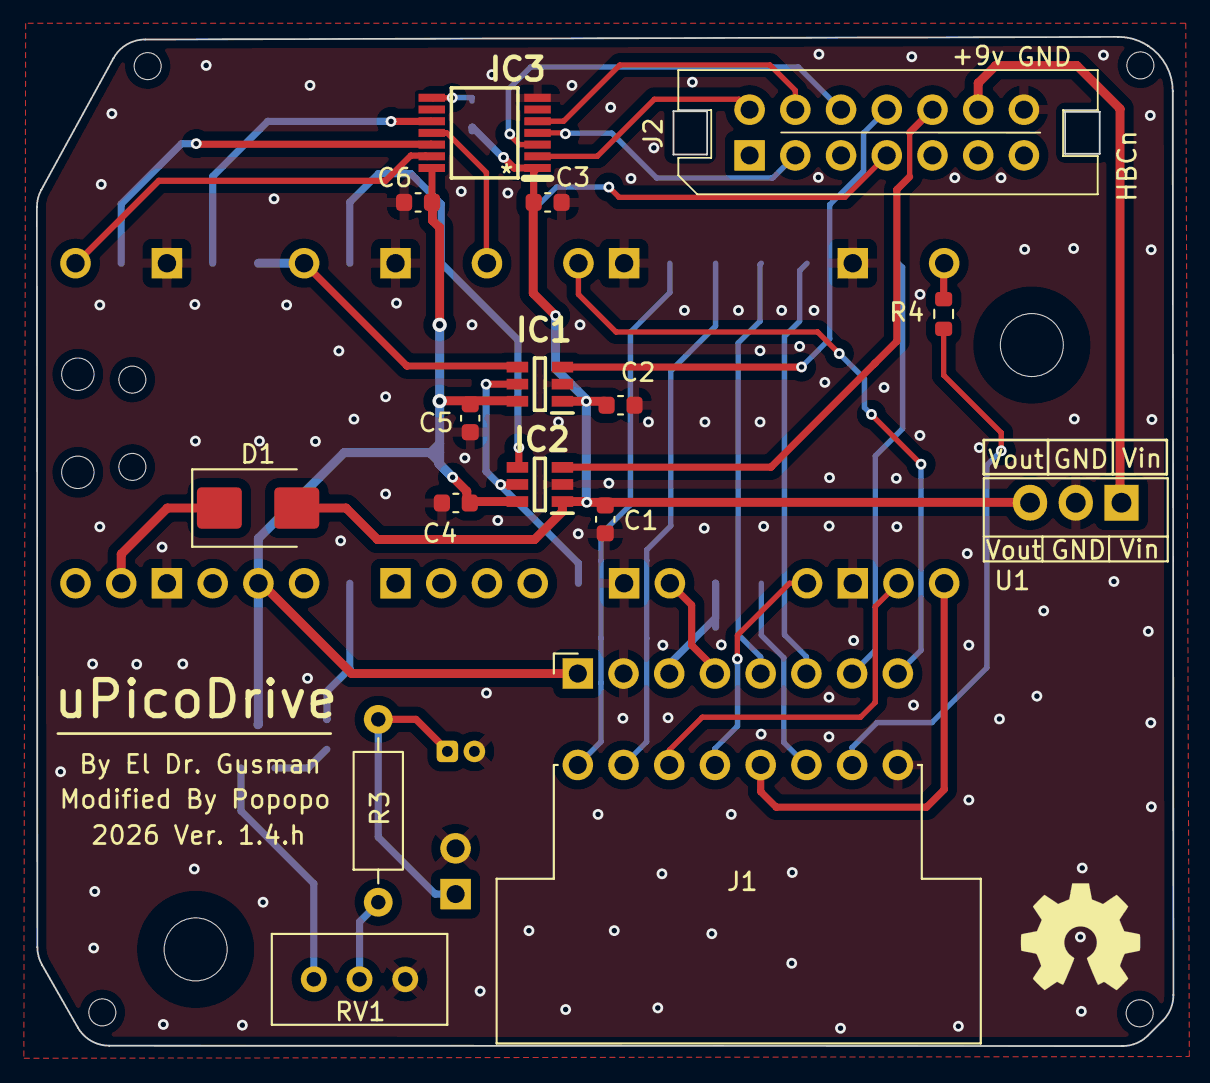
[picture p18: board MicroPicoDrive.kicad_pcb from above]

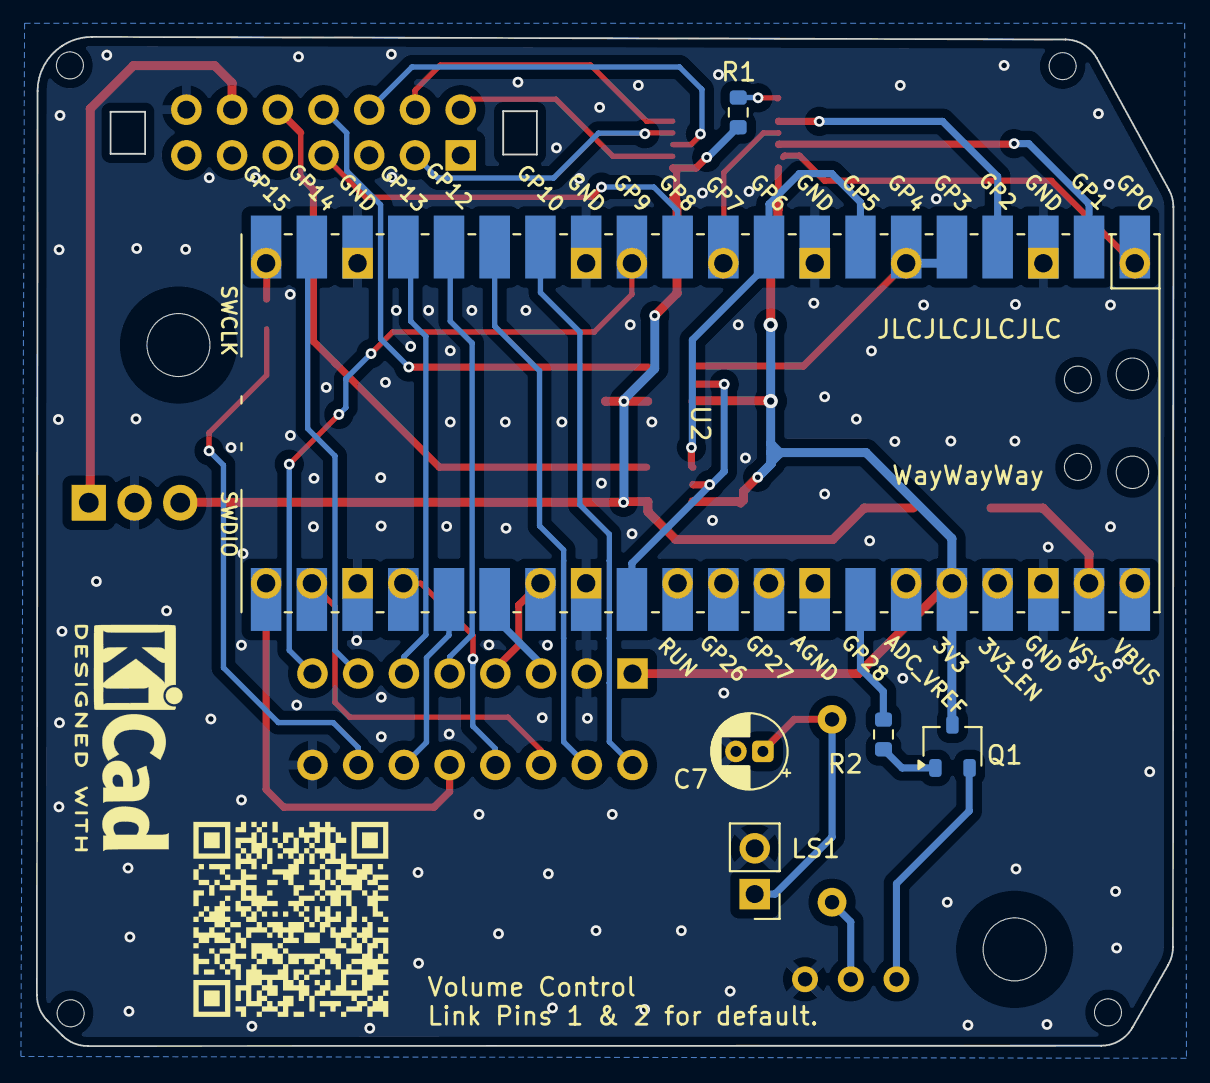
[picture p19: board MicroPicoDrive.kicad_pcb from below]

Board: 2 copper layers, 63.1 x 56.1 mm, 30 parts (7 on the bottom side), 39 nets.

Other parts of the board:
Log_KiCad: KiCad-Logo2_5mm_SilkScreen
Log_OpenHardware: OSHW-Symbol_6.7x6mm_SilkScreen
MH1, MH2: MountingHole; MountingHole_3.5mm_safe_screw_area
MH_S1, MH_S2, MH_S3, MH_S4: MountingHole

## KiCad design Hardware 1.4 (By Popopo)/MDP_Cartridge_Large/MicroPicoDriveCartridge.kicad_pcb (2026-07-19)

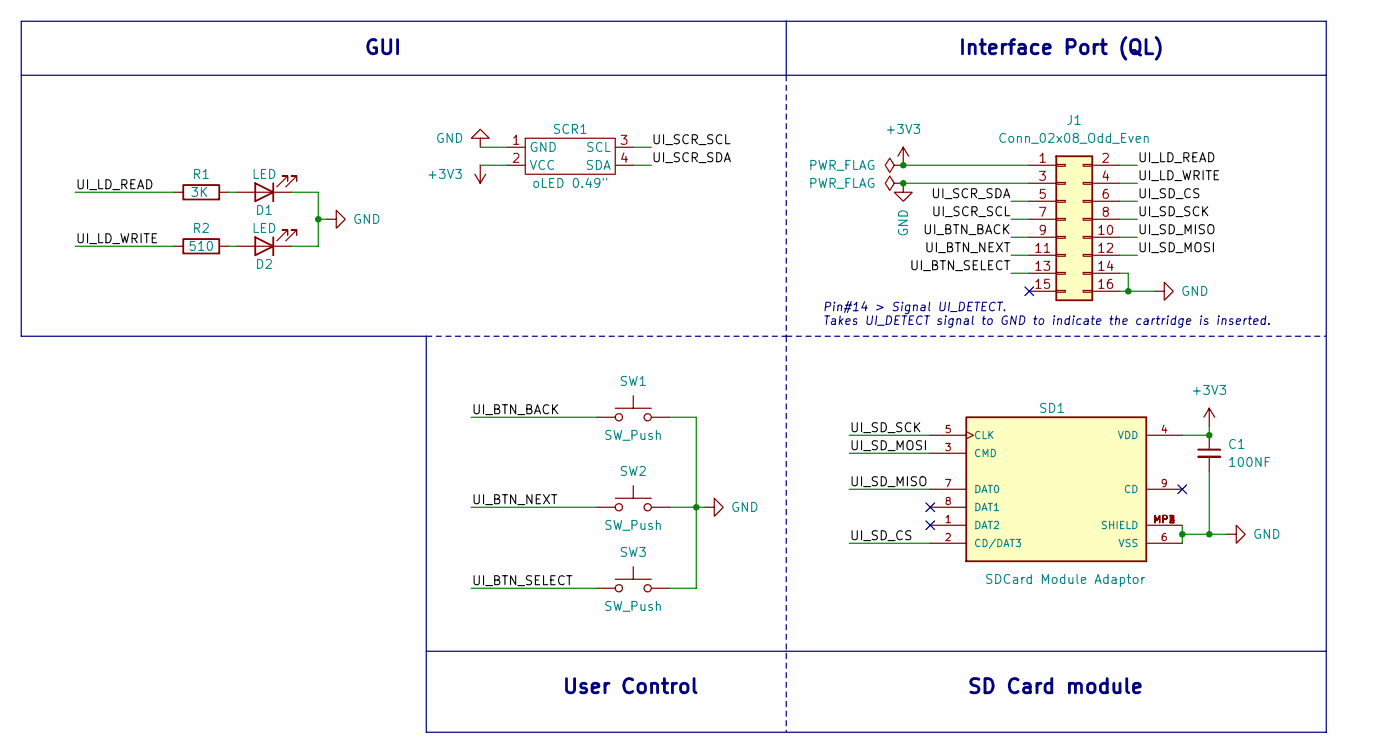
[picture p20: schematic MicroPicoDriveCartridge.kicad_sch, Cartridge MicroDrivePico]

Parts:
C1: 100NF; C_0603_1608Metric_Pad1.08x0.95mm_HandSolder
D1, D2: LED; LED_D3.0mm
J1: Conn_02x08_Odd_Even; Edge 2x8pin Male
R1: 3K; R_0603_1608Metric
R2: 510; R_0603_1608Metric
SCR1: oLED 0.49"; Screen
SD1: SDCard Module Adaptor; SDCard_Module_changed
SW1, SW2, SW3: SW_Push; SW_SPST_PTS645Sx43SMTR92

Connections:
+3V3: C1.1, J1.1, SCR1.2 (VCC), SD1.4 (VDD)
/UI_BTN_BACK: J1.9, SW1.1
/UI_BTN_NEXT: J1.11, SW2.1
/UI_BTN_SELECT: J1.13, SW3.1
/UI_LD_READ: J1.2, R1.1
/UI_LD_WRITE: J1.4, R2.1
/UI_SCR_SCL: J1.7, SCR1.3 (SCL)
/UI_SCR_SDA: J1.5, SCR1.4 (SDA)
/UI_SD_CS: J1.6, SD1.2 (CD/DAT3)
/UI_SD_MISO: J1.10, SD1.7 (DAT0)
/UI_SD_MOSI: J1.12, SD1.3 (CMD)
/UI_SD_SCK: J1.8, SD1.5 (CLK)
GND: C1.2, D1.1 (K), D2.1 (K), J1.3, J1.14, J1.16, SCR1.1 (GND), SD1.6 (VSS), SD1.MP1 (SHIELD), SD1.MP2 (SHIELD), SD1.MP3 (SHIELD), SD1.MP4 (SHIELD), SW1.2, SW2.2, SW3.2
unnamed: D1.2 (A), R1.2
unnamed: D2.2 (A), R2.2

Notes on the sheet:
GUI
Pin#14 > Signal UI_DETECT. Takes UI_DETECT signal to GND to indicate the cartridge is inserted.
Interface Port (QL)
User Control
SD Card module

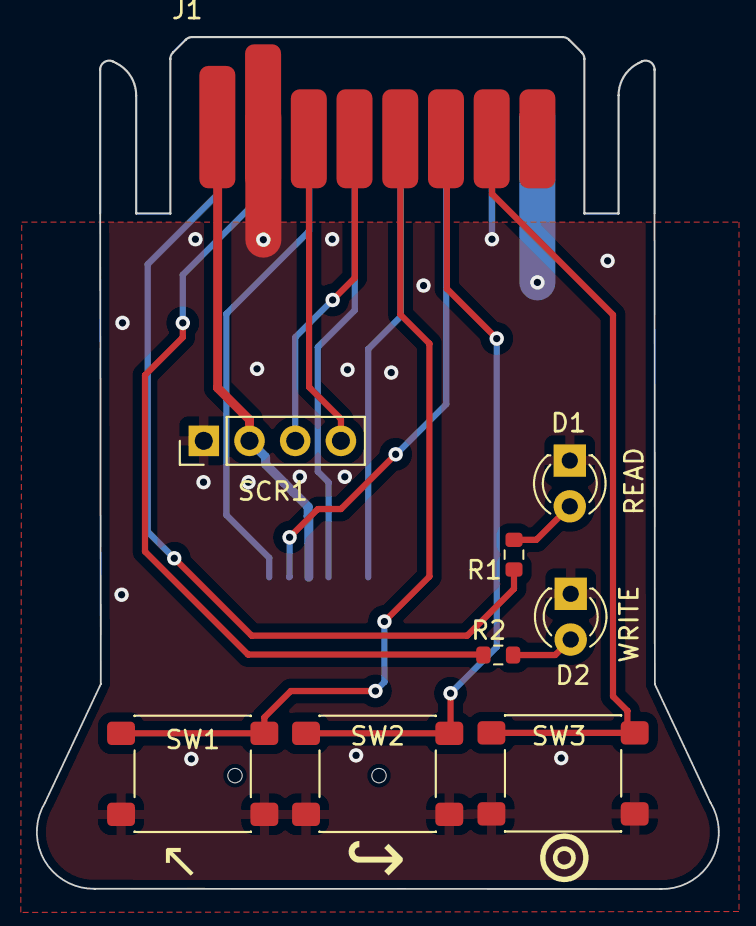
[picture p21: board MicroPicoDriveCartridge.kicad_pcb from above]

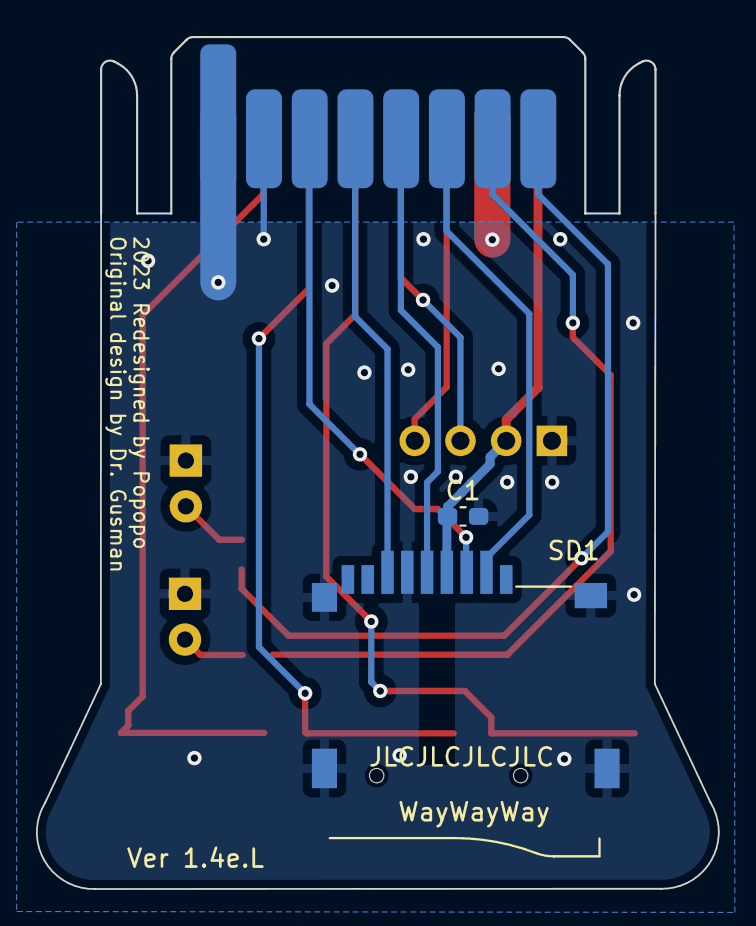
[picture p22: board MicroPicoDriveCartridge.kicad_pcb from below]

Board: 2 copper layers, 37.9 x 47.3 mm, 11 parts (2 on the bottom side), 15 nets.

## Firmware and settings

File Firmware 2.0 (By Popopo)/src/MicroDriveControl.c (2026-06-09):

//TODO: Momento de comenzar a estudiar, documentar y trabajar, factorizar este código.

#include "hardware/pio.h"
#include "hardware/gpio.h"
#include "hardware/irq.h"
#include "hardware/dma.h"
#include "hardware/timer.h"
#include "MicroDriveControl.h"
#include "SharedBuffers.h"
#include "SharedEvents.h"
#include "EventMachine.h"
#include "PIO_machines.pio.h"

bool isCartridgeInserted = false;
bool secondBufferSet = false;

mdstatus_t mdStatus = MDS_DESELECTED;
mdactivestatus_t activeStatus = MDA_IDLE;
mdmediastate_t mdMediaState = MD_MEDIA_NONE;

evtmachine_t mdEventQueue;

uint track1DMA;
uint track2DMA;

bool track1DMAFired = false;
bool track2DMAFired = false;

dma_channel_config track1ReadConfig;
dma_channel_config track2ReadConfig;

dma_channel_config track1WriteConfig;
dma_channel_config track2WriteConfig;

dma_channel_config track1DisabledConfig;
dma_channel_config track2DisabledConfig;

uint rxProgramOffset;
uint statProgramOffset;
uint txProgramOffset;
uint shiftProgramOffset;

int sm_read_head_1;
int sm_read_head_2;
int sm_status;
int sm_exec_read;

int sm_write_head_1;
int sm_write_head_2;
int sm_shifter;
int sm_exec_write;

/**
 * Helper to know the MD activity status of reading.
 */
static inline bool is_read_state(mdactivestatus_t s){
    //FIXME: it should be like this, always return TRUE, but if I change it, the code doesn't work
    //Giving always BAD OR CHANGED MEDIUM after a DIR 

    // return s == MDA_READ_HEADER || s == MDA_READ_HEADER_GAP ||
    //        s == MDA_READ_SECTOR || s == MDA_READ_SECTOR_GAP;
    return activeStatus >= MDA_READ_HEADER || activeStatus <= MDA_READ_SECTOR;
    
}

/**
 * Helper to know the MD activity status of writting
 */
static inline bool is_write_state(mdactivestatus_t s){
    //FIXME: it should be like this, always return TRUE, but if I change it, the code doesn't work
    //Giving always BAD OR CHANGED MEDIUM after a DIR 

    // return s == MDA_WRITE_HEADER || s == MDA_WRITE_HEADER_GAP ||
    //        s == MDA_WRITE_SECTOR || s == MDA_WRITE_SECTOR_GAP;
    return activeStatus >= MDA_WRITE_HEADER_GAP || activeStatus <= MDA_WRITE_SECTOR;
}

//enable the microdrive
void select_md() {
    //Change the md status to active
    mdStatus = MDS_SELECTED;
    //Enable the status machine
    select_PIO_status();
    //Notify to the UI
    mtuevent_t evt;
    evt.event = MTU_MD_SELECTED;
    event_push(&mdToUiEventQueue, &evt);
}

//disable the microdrive
void deselect_md() {
    //Reset the select status
    mdStatus = MDS_DESELECTED;
    //We store the previous state to check if we need to notify the UI about any buffer change
    mdactivestatus_t previousState = activeStatus;
    //We reset the active status, this may cause the last buffer that was being read or written
    //to be sent again to the ULA if it was a header, but this should not cause any trouble as the QL
    //does not deselect the drive while it's doing a write/format operation
    activeStatus = MDA_IDLE;
    //Abort the alarms if pending
    abort_shifter_alarm();
    abort_write_gap_alarm();
    //Ensure both transfer machines are idle
    sleep_PIO_write();
    begin_PIO_read_gap();
    //Disable the status machine
    deselect_PIO_status();
    //Disable the DMAs if they're active
    if(is_read_state(activeStatus))
        disable_DMAs(true);
    else if(is_write_state(activeStatus))
        disable_DMAs(false);

    //Set dir to input to avoid problems
    gpio_put(MD_HEAD_DIR, 1);
    //Check for any buffer change. This is mostly by sanity, the MD should not deselect the device while it's
    //writting to the md and if we send again the same sector to the ULA it will skip it if needed
    check_ui_notifications(previousState, false);
    //Notify to the UI about the device deselection
    mtuevent_t evt;
    evt.event = MTU_MD_DESELECTED;
    event_push(&mdToUiEventQueue, &evt);
}

//This function checks if the UI needs to be notified about any buffer change event
//This is called at the beginning of the gaps and when the device is deselected
void check_ui_notifications(mdactivestatus_t previousState, bool fromGap) {
    switch(previousState) {
        case MDA_READ_SECTOR:   //We were reading a sector from the ULA, notify the UI that it needs to write the buffers to the cartridge
                                //image and fill the buffers with the next sector
        {
            mtuevent_t readEvt;
            readEvt.event = MTU_BUFFERSET_WRITTEN;
            //If we are called from a gap routine the buffer set has already been changed
            //but if we are being called from the deselection method then the bufferset has not been changed.
            if(fromGap) readEvt.arg = secondBufferSet ? 0 : 1;
            else readEvt.arg = secondBufferSet ? 1 : 0;
            event_push(&mdToUiEventQueue, &readEvt);
        }
            break;

        case MDA_WRITE_SECTOR:  //We were writting a sector to the ULA, notify the UI that it needs to fill the buffers with the next sector
        {
            mtuevent_t writeEvt;
            writeEvt.event = MTU_BUFFERSET_READ;
            //If we are called from a gap routine the buffer set has already been changed
            //but if we are being called from the deselection method then the bufferset has not been changed.
            if(fromGap) writeEvt.arg = secondBufferSet ? 0 : 1;
            else writeEvt.arg = secondBufferSet ? 1 : 0;
            event_push(&mdToUiEventQueue, &writeEvt);
        }
            break;
        default:
            break;

    }

    switch(activeStatus){
        case MDA_READ_HEADER_GAP:
        case MDA_READ_SECTOR_GAP: {
            mtuevent_t readEvt;
            readEvt.event = MTU_MD_READING;
            event_push(&mdToUiEventQueue, &readEvt);
        }
            break;

        case MDA_WRITE_HEADER_GAP:
        case MDA_WRITE_SECTOR_GAP: {
            mtuevent_t writeEvt;
            writeEvt.event = MTU_MD_WRITTING;
            event_push(&mdToUiEventQueue, &writeEvt);
        }
            break;
        default:
            break;
    }
}
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

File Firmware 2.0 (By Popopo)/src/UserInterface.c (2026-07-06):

/**
 * This module define and structure the GUI and controls of the
 * device throught the cartridge with the user.
 * Also it contains funtions that are part of the control module.
 *
 * @Author: Dr. Gusman
 * @Author: Modified by Popopo
 * @Version: 1.4.3
 * @date: 31/03/2025
 */

#include <string.h>
#include <stdio.h>
#include "EventMachine.h"
//
#include "UserInterface.h"
#include "SharedBuffers.h"
#include "SharedEvents.h"
#include "View.h"
#include "IO_Cart.h"
//
#define IS_CART_OUT() gpio_get(PIN_UI_DETECT)				//Detect Cartridge disconected. TRUE if disconected, FALSE in other case
#define BTN_PRESSED(BUTTON) (!gpio_get(BUTTON))				//Detect Button pressed. TRUE if pressed, FALSE in other case

USER_INTERFACE_STATE uiState = IDLE;
USER_INTERFACE_STATE uiNextState;

uint64_t delayEnd;
bool FirstBoot = true;										//Flag to detect if the MDP is booted by first time or not. That is important to define the behaviour.

//Process events from the MD control
void process_md_to_ui_event(void* event) {
    mtuevent_t* evt = (mtuevent_t*)event;

    switch(evt->event) {
        case MTU_MD_DESELECTED:
            mdInUse = false;
            setInFormat(false);
            SET_LED_OFF(LED_SELECT);
            SET_LED_OFF(LED_READ);
            SET_LED_OFF(LED_WRITE);
            break;
        case MTU_MD_SELECTED:
            mdInUse = true;
            SET_LED_ON(LED_SELECT);
            break;
        case MTU_MD_READING:
            SET_LED_ON(LED_READ);
            SET_LED_OFF(LED_WRITE);
            break;
        case MTU_MD_WRITTING: //TODO: Alternative point that could be a nice place to direct writting function
            SET_LED_ON(LED_WRITE);
            SET_LED_OFF(LED_READ);
            break;
        case MTU_BUFFERSET_READ:
            process_md_read(evt->arg);
            break;
        case MTU_BUFFERSET_WRITTEN: //TODO: Here could be a nice place to direct writting function too
            process_md_write(evt->arg);
            break;
    }
}

/**
 * This function go to the next file on the FS that is valid to browse.
 * It means, directories, MDV and MDP images.
 * For that purpose it moves the pointer to the next FS entry, ignoring the non-selectable files.
 * @return FRESULT res with the result of the operation.
 */
FRESULT nextEntry(){
	FRESULT res = nextFSEntry();
	//Firsly check if there is a entry and if it is not null (what means there is not another file).
	if( res == FR_OK && fno.fname[0] == 0) {
		//Not valid one, it is null reference due to last file in the table.
		//So do nothing.
		showMSG(NO_MORE_FILES);
	}else if (res == FR_OK && isSelectable()){
		//If it is an valid file then show the name too.
		show_file_name(fno.fname,IN_FOLDER);
	}
	
	return res;
}

/**
 * Debounce a button pressed.
 * It gives some sleeping process time to ignore extra holding time when pressing a button.
 * When the button is the button 'NEXT' instead of debounce completealy, it adds some latency
 *  and the behavior of read the new FS entry. Allowing a softer file browsing.
 * @param button The button to apply debounce.
 */
void debounce_button(uint button) {
	FRESULT res;
    while(BTN_PRESSED(button)){ 
		sleep_ms(20); 
		//When the button is 'Next', it skip the entry and goes to the next one after a holding time (retard).
		if(button == PIN_BTN_NEXT ){
			sleep_ms(200);
			//If it continues pressed then read the next FS entry.
			if(BTN_PRESSED(button) && res != FR_NO_FILE) {
				//Just in case there are not more files, ignore next reading till debounce it.
				res = nextEntry();
			}
		}
	}
    sleep_ms(200);
}

/**
 * It defines the actions for the BACK button.
 * When it is pressed the function get back in the path and reset the file values if any was selected before.
 * The function also cancels the operations programmed in the schedule (if any)
 */
void doBack(){
	debounce_button(PIN_BTN_BACK);
	rewind_path();
	uiState = OPEN_FOLDER;
	crt_type = NONE;
	utmevent_t removeEvt;
	setCurrectSector(0);  // The only difference with script into the press button function in process_user_interface function.
	removeEvt.event = UTM_CARTRIDGE_REMOVED;
	event_push(&uiToMdEventQueue, &removeEvt);
}

void program_delay(uint64_t ms_delay, USER_INTERFACE_STATE nextState){
    delayEnd = time_us_64() + (ms_delay * 1000);
    uiNextState = nextState;
    uiState = DELAY;
}

/**
 * The function checks if the delay time was reached.
 * While it awaits, make the power led flash continuously.
 * @return TRUE if the time was reached. Otherwise FALSE.
 */
bool check_delay(){
	bool done = false;
    uint64_t currentTime = time_us_64();
    if(currentTime >= delayEnd)	{
		uiState = uiNextState;
		done = true;
	}
	return done;
}
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

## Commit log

2023-12-24 borrados: MicroPicoDrive/MicroPicoDrive-backups/MicroPicoDrive-2023-12-21_160440.zip modificados: MicroPicoDrive/MicroPicoDrive.kicad_pcb modificados: MicroPicoDrive/MicroPicoDrive.kicad_prl modifica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
    [MicroPicoDrive.kicad_pcb]
2024-06-23 Add files via upload
    My Version of PCBs and Firmware
    [MicroPicoDrive-B_Cu.gbl, MicroPicoDrive-B_Mask.gbs, MicroPicoDrive-B_Paste.gbp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]
2024-06-29 WiP re-structure github
    [MicroPicoDrive.kicad_pcb, MicroPicoDriveCartridge.kicad_pcb, MicroPicoDriveCartridge.kicad_sch]
2024-07-01 updating info 4
    [MicroPicoDrive-B_Cu.gbl, MicroPicoDrive-B_Mask.gbs, MicroPicoDrive-B_Paste.gbp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]
2024-07-07 RC8 ignores non valid files and next button change behavior
    [CONFIG.CFG]
2024-07-08 bugfix DMA and little changes
    [MicroDriveControl.c, UserInterface.c]
2024-07-11 SCRM2 and bugfixes 2
    [MicroDriveControl.c, UserInterface.c]
2024-08-05 RC11 WiP 3 and new MDVs for testing
    [CONFIG.CFG]
2024-08-12 RC11 with bugfix in frozen last FSEntry file
    [UserInterface.c, View.c, View.h]
2024-12-01 MDVs demos updated
    [CONFIG.CFG, MicroPicoDrive.kicad_pcb, MicroPicoDrive.kicad_sch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]
2024-12-07 fixing bug and refactoring
    [UserInterface.c, View.c]
2024-12-16 RC13 bugfix when not config file and bugfix in IO function loaddirectly in return value
    [UserInterface.c, View.c]
2025-03-28 RC14: fixed some bugs, working in fixing inherited bugs
    [MicroDriveControl.c, UserInterface.c, View.c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]
2026-05-10 adding diode VSYS
    [MicroPicoDrive.kicad_pcb, MicroPicoDrive.kicad_sch]
2026-05-12 new rev.f ready
    [MicroPicoDrive.kicad_pcb]
2026-06-09 new diode tested
2026-06-10 Revision driver and firmware, left cartridge rev.e real test
    [MicroPicoDrive.kicad_sch, MicroPicoDriveCartridge.kicad_pcb, MicroPicoDriveCartridge.kicad_sch]
2026-06-13 recovering hard format
    [MicroPicoDrive.kicad_pcb, MicroPicoDrive.kicad_sch, MicroPicoDriveCartridge.kicad_pcb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]
2026-06-15 changing DRC and PCB references 1
    [MicroPicoDrive.kicad_pcb, MicroPicoDrive.kicad_sch]
2026-06-16 changing DRC and PCB references 2
    [MicroPicoDrive-B_Cu.gbl, MicroPicoDrive-B_Mask.gbs, MicroPicoDrive-B_Paste.gbp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]
2026-07-07 removing rivets
    [MicroPicoDrive.kicad_pcb]
2026-07-09 finished driver PCB rev h
    [MicroPicoDrive-B_Cu.gbl, MicroPicoDrive-B_Mask.gbs, MicroPicoDrive-B_Paste.gbp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]
2026-07-12 Last changes on dev PCBs
    [MicroPicoDriveCartridge-B_Cu.gbl, MicroPicoDriveCartridge-B_Mask.gbs, MicroPicoDriveCartridge-B_Paste.gbp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]
2026-07-19 last changes
    [MicroPicoDrive.kicad_pcb, MicroPicoDriveCartridge.kicad_pcb]
